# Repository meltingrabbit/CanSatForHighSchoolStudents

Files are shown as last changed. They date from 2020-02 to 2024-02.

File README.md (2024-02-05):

<!-- README.md -->
# 高校生のためのCanSat開発キット
CanSat for High School Students  
高校生のためのCanSat開発キット

**最新版の開発・メンテはフォーク先の [ut-issl/CanSatForHighSchoolStudents](https://github.com/ut-issl/CanSatForHighSchoolStudents) にて行われています．**

## リンク
[GitHub](https://github.com/meltingrabbit/CanSatForHighSchoolStudents)  
[Web Page](https://meltingrabbit.github.io/CanSatForHighSchoolStudents/)

## 概要
+ 高校生向け缶サット開発キット
+ [Arduino Nano Every](https://store.arduino.cc/usa/nano-every-with-headers)を想定
	- Arduino Nanoでも可能だが，よりSRAMの多いEveryを用いたほうがよい．

### Ver.2.2 （2023年版）
Ver.2.1 から，マイクを追加するなどのマイナーアップデートをしたバージョン．

### Ver.2.1 （2022年版）
Ver.2 から，半導体不足等で入手困難なセンサ類を変更したバージョン．

### Ver.2 （2021年版）
+ Ver.1で難易度の高かった配線を簡易化するため，すべての階層に同じマイコンのピンをストレートで伸ばしたもの．
+ これにより，層の順番の変更や，取捨選択が可能となった．

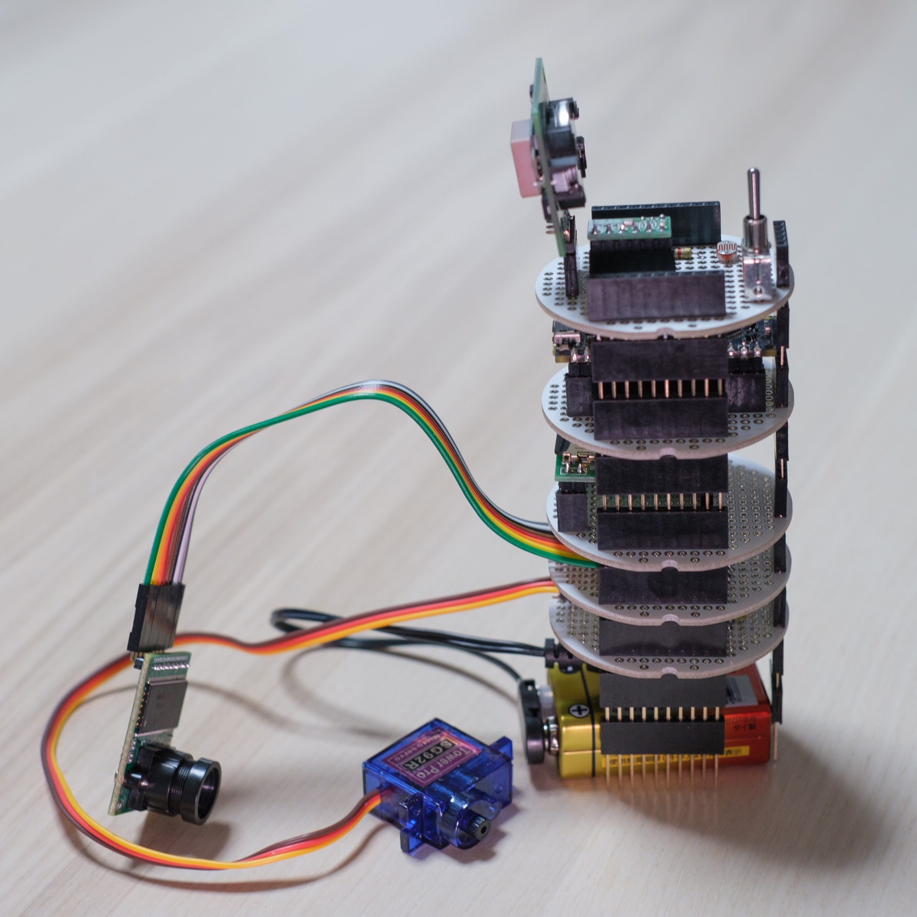
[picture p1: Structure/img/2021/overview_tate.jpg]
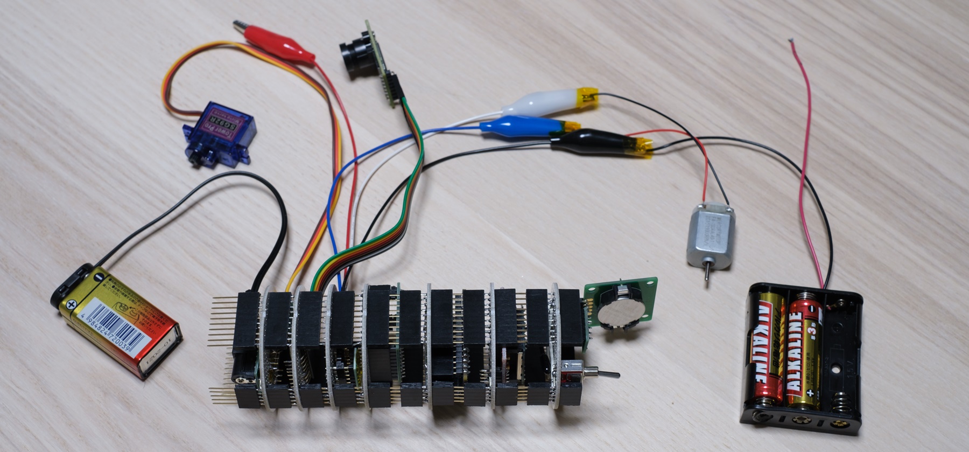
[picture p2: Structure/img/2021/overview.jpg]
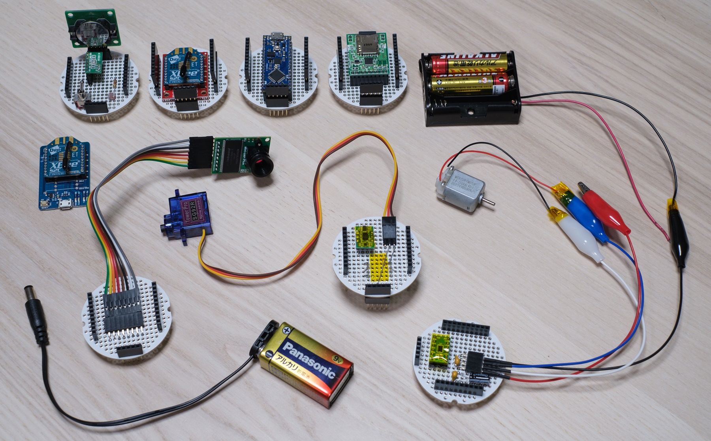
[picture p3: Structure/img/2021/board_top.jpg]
  

### Ver.1 （2020年版）
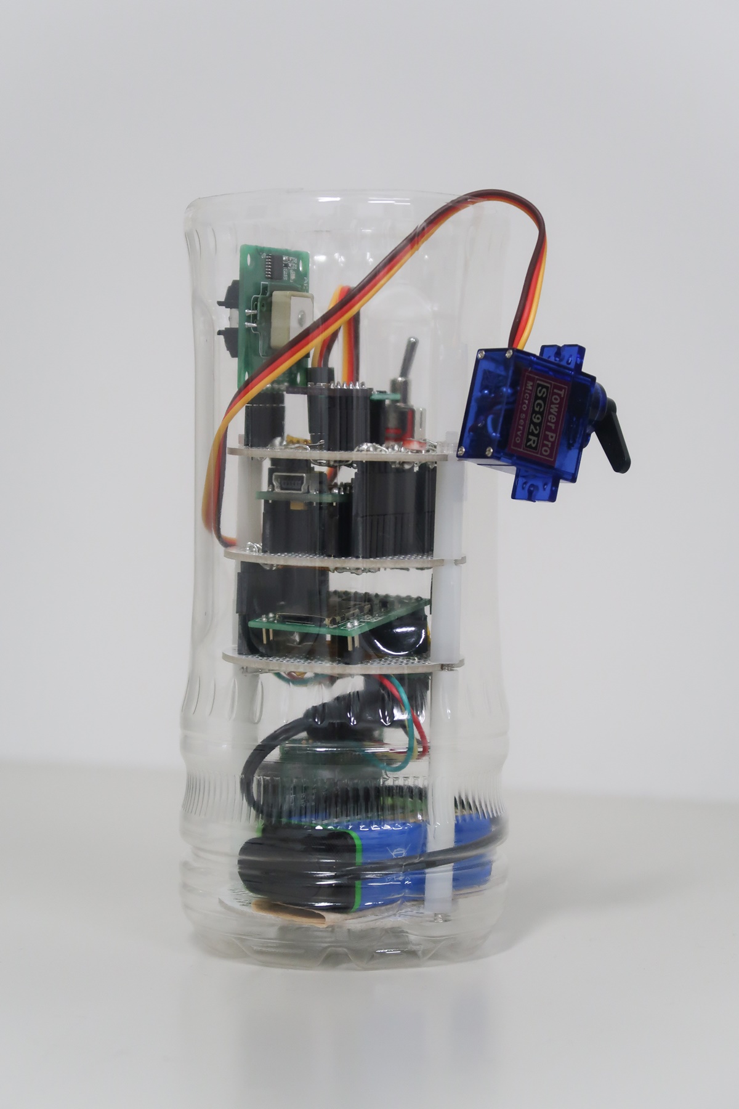
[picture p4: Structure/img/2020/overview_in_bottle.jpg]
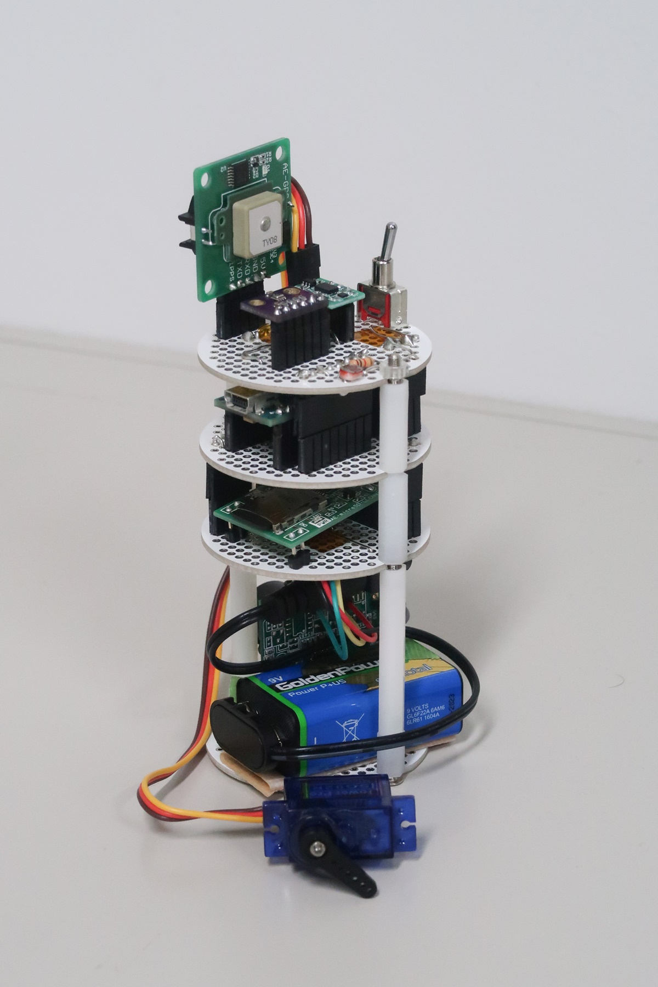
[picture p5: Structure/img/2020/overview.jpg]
 
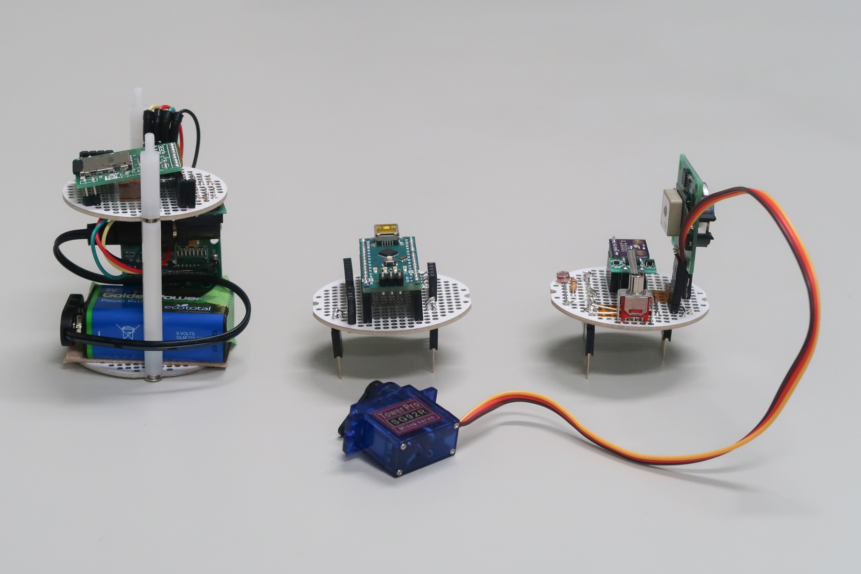
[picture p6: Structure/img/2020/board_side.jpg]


### 利用について
本資料の活用については制限しておりませんが，その際には以下までご一報いただければ幸いです．
+ melting.rabbit.mr[at]gmail.com

## 搭載機器
機器の詳細な型番などは[パーツリスト](./Structure/PartsList)を参照のこと．

### センサ
+ GPS
+ 9軸センサ
+ 高度計（気圧計）
+ 温湿度計
+ 光センサ
+ カメラ
+ マイク

### アクチュエータ
+ サーボモータ
+ DCモータ

### 通信機
+ XBee

### ストレージ
+ SDカード

## 資料一覧
+ `./Arduino` ：サンプルコードとその設定など
	- [Arduinoについて](./Arduino/)
	- 機器のテストコード（動作試験）
		* [GPSの単体テスト](./Arduino/Test_GPS)
		* [9軸センサ (IMU) の単体テスト (BMX055)](./Arduino/Test_IMU)
		* [9軸センサ (IMU) の単体テスト (Pololu MinIMU-9 v5)](./Arduino/Test_IMU_Pololu)
		* [高度計（気圧計）・温湿度計の単体テスト](./Arduino/Test_Barometer_Thermohygrometer)
		* [光センサの単体テスト](./Arduino/Test_Light)
		* [カメラの単体テスト](./Arduino/Test_Camera2)
		* [マイクの単体テスト](./Arduino/Test_Microphone)
		* [サーボモータの単体テスト](./Arduino/Test_Servo)
		* [DCモータの単体テスト](./Arduino/Test_DCMotor)
		* [SDカードの単体テスト](./Arduino/Test_SD)
		* [XBee（無線通信機）の単体テスト](./Arduino/Test_XBee)
		* 過去
			+ [カメラ（2020年使用版）の単体テスト](./Arduino/Test_Camera_2020)
			+ [高度計（気圧計）（2020年使用版）の単体テスト](./Arduino/Test_Barometer)
	- 機器のテストコード（複数使用）
		* [全機器の統合状態のテスト](./Arduino/Test)
		* [光センサを４並列にした光方向センサ](./Arduino/Test_Light_x4)
		* [サーボモータの２並列版](./Arduino/Test_Servo_x2)
		* [DCモータの２並列版](./Arduino/Test_DCMotor_x2)
	- プログラミング講習
		* [00. 事前準備](./Arduino/ProgrammingTutorial00_Preparation)
		* [01. HelloWorld](./Arduino/ProgrammingTutorial01_HelloWorld)
		* [02. Variable](./Arduino/ProgrammingTutorial02_Variable)
		* [03. Operator](./Arduino/ProgrammingTutorial03_Operator)
		* [04. If Else](./Arduino/ProgrammingTutorial04_IfElse)
		* [05. Loop](./Arduino/ProgrammingTutorial05_Loop)
		* [06. Function](./Arduino/ProgrammingTutorial06_Function)
		* [07. Device1 （高度計）](./Arduino/ProgrammingTutorial07_Device1)
		* [08. Device2 （方位磁石）](./Arduino/ProgrammingTutorial08_Device2)
		* [09. Device3 （サーボモータの利用）](./Arduino/ProgrammingTutorial09_Device3)
		* [10. Application （明るさ計）](./Arduino/ProgrammingTutorial10_Application)
	- 実装例
		* [明るさ計](./Arduino/App_LightMeter)
+ `./Schematic` ：[回路図](./Schematic)
+ `./Structure` ：[構造など](./Structure)
	- [パーツリスト](./Structure/PartsList)
	- [ユニ基板詳細](./Structure/board)
	- [電源スイッチ](./Structure/switch)
	- [テスタ](./Structure/tester)
+ `./Archives` ：アーカイブ
	- [2020年02月22～23日 缶サットHigh School 「缶サット電子系講座」](./Archives/2020-02-22_Fukui)
	- [2021年06月19～20日 缶サットHigh School 「缶サット構造系講座」](./Archives/2021-06-19_Fukui)
	- [2022年03月19～20日 缶サットHigh School 「缶サット電子系講座」](./Archives/2022-03-19_Fukui)
	- [2023年02月18～19日 缶サットHigh School 「缶サット電子系講座」](./Archives/2023-02-18_Fukui)

## ブログ
+ [【CanSat】缶サット甲子園を目指す高校生向け電子系講座 2020年度版 @福井 [2020/02/23]](https://meltingrabbit.com/blog/article/2020022301/)
+ [【CanSat】缶サット甲子園を目指す高校生向け構造系講座 2020年度版 @福井 [2020/10/25]](https://meltingrabbit.com/blog/article/2020102501/)
+ [【CanSat】缶サット甲子園を目指す高校生向け電子系講座 2021年度版 @福井 [2021/02/14]](https://meltingrabbit.com/blog/article/2021021401/)
+ [【CanSat】缶サット甲子園を目指す高校生向け構造系講座 2021年度版 @福井 [2021/06/20]](https://meltingrabbit.com/blog/article/2021062001/)
+ [【CanSat】缶サット甲子園を目指す高校生向け電子系・構造系講座 2022年度版 @福井 [2022/06/19]](https://meltingrabbit.com/blog/article/2022061901/)

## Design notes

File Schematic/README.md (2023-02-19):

# 回路図
詳細は，各機器の動作試験コードのページを参照
+ [GPS](../Arduino/Test_GPS)
+ [9軸センサ](../Arduino/Test_IMU)
+ [高度計（気圧計）・温湿度計](../Arduino/Test_Barometer_Thermohygrometer)
+ [光センサ](../Arduino/Test_Light)
+ [カメラ](../Arduino/Test_Camera2)
+ [マイク](../Arduino/Test_Microphone)
+ [サーボモータ](../Arduino/Test_Servo)
+ [DCモータ](../Arduino/Test_DCMotor)
+ [SDカード](../Arduino/Test_SD)
+ [XBee（無線通信機）](../Arduino/Test_XBee)
+ [全機器の統合状態](../Arduino/Test)
+ 過去
	- [カメラ](../Arduino/Test_Camera_2020)
	- [高度計（気圧計）](../Arduino/Test_Barometer)

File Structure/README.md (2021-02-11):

# 構造
## 概要
+ ユニバーサル基板を用いて配線と構造を組む
+ [詳細画像はこちら](./board)
<!--
![](./overview_in_bottle.jpg)
![](./overview.jpg)
![](./board_side.jpg)
![](./board_top.jpg)
-->

### Ver.2 （2021年版）
+ Ver.1で難易度の高かった配線を簡易化するため，すべての階層に同じマイコンのピンをストレートで伸ばしたもの．
+ これにより，層の順番の変更や，取捨選択が可能となった．

  

マイコン層のピンアサインは以下の通り．
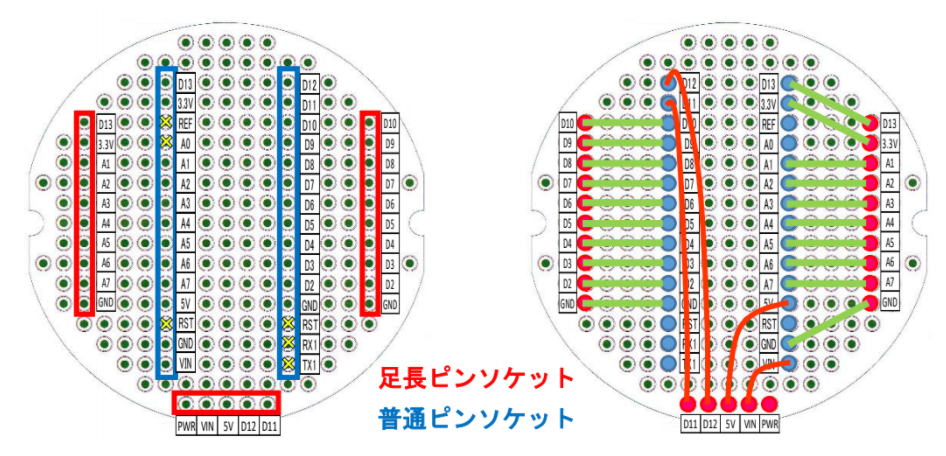
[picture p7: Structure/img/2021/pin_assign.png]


### Ver.1 （2020年版）
 


## パーツ
[電源スイッチ](./switch)

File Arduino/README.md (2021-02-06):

# Arduinoについて
## 概要
[Arduino](https://www.arduino.cc/)とは，電子工作初心者にも使いやすいマイコンであり，C言語風のプログラムによってソフトウェアを書く．  
特徴は以下．

+ 電子工作のデファクトであり，対応するセンサも多い．
+ コミュニティが広く，サンプルコードなどがたくさん出回っている．
+ 5V系であるため，近年主流となっている3.3V系のセンサを用いる場合はレベル変換が必要．

様々な種類があるが，CanSatには小型なNanoシリーズが適している．

## Arduino Nano
[Arduino Nano](https://store.arduino.cc/usa/arduino-nano)．  
標準的なUNOより小型なボード．

- ATmega328P搭載
	- Flashメモリ: 32 KB 内2KBはブートローダーで使用
	- SRAM: 2 KB
	- EEPROM: 1 KB
	- Clock Speed: 16 MHz
- 動作電圧: 5 V
- 入力電源電圧(推奨): 7～12 V
- デジタル入出力ピン: 14本
- PWMチャンネル: 6本
- アナログ入力チャンネル: 8本
- 直流電流(1ピン当り最大): 40 mA
- 直流電流(3.3Vピン、1ピン当り最大): 50 mA

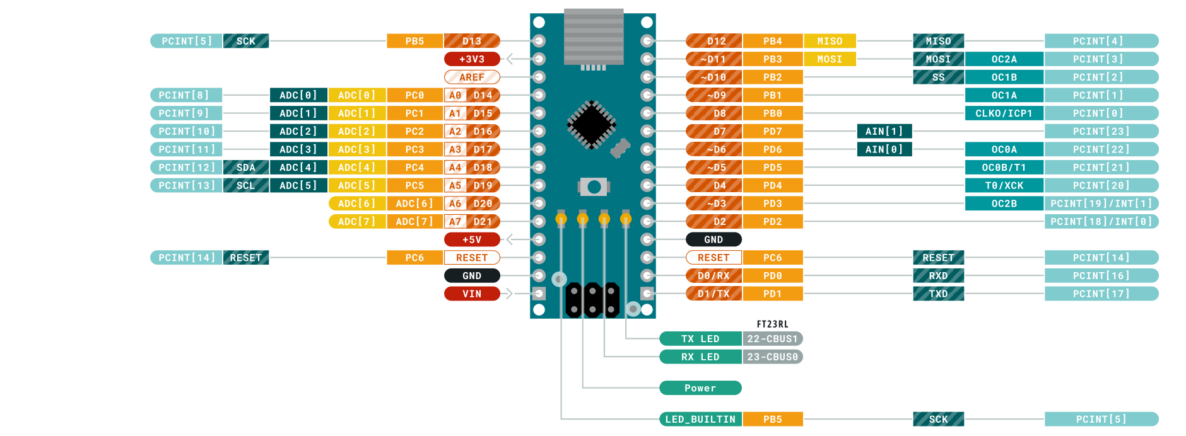
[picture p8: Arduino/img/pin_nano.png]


## Arduino Nano Every
[Arduino Nano Every](https://store.arduino.cc/usa/nano-every-with-headers)．  
Arduino Nanoと同じフットプリントで高性能になった，Arduino Nanoの後継機である．

CanSatとしては，Nanoと比べてSRAMが3倍になっているのが嬉しい．  
これにより，たくさんのセンサを同時に駆動できるようになった．

- ATMega4809搭載
	- CPU Flash Memory 48 KB
	- SRAM 6KB
	- EEPROM 256byte
- 動作電圧：5 V
- 外部入力電源電圧（推奨）: 7 ～ 12 V
- I/Oピン最大電流：20 mA
- 3.3 Vピン最大電流：50 mA
- 動作周波数：20 MHz
- PWM ピン数；5 （D3, D5, D6, D9, D10）
- UART x 1
- SPI x 1
- I2C x 1
- アナログ入力ピン数 x 8 （ADC 10 bit）
- 寸法；45 mm x 18 mm

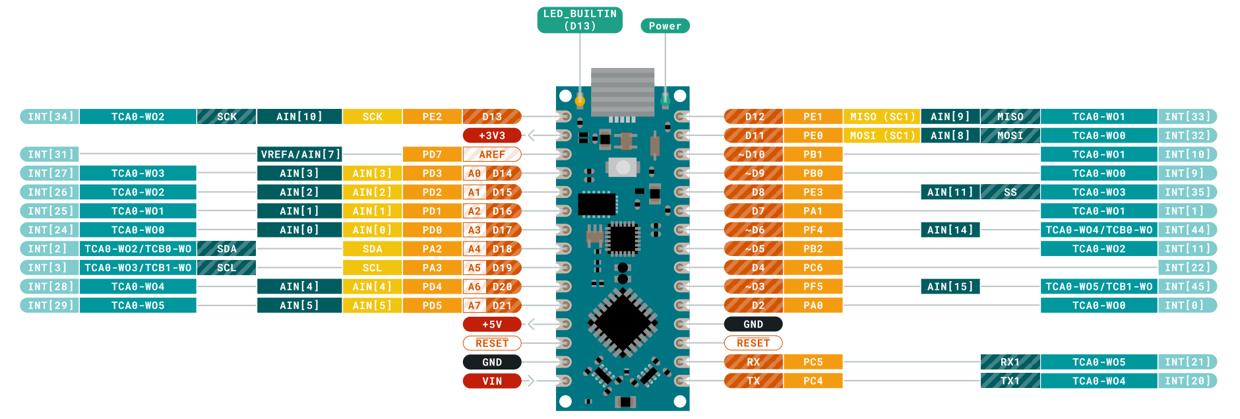
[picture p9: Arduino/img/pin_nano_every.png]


## GitHubへのリンク
[GitHub](https://github.com/meltingrabbit/CanSatForHighSchoolStudents/tree/master/Arduino)

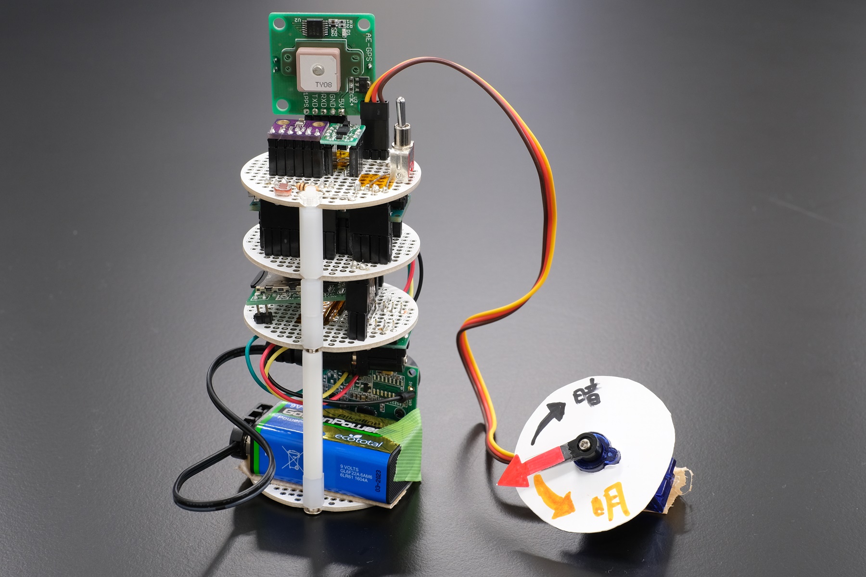
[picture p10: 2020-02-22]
Arduino/App_LightMeter/img/overview.JPG

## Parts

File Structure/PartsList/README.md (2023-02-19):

# パーツリスト
## マイコン
| パーツ名 | 型番 | 概要 | 購入先URL |
| :--- | :--- | :--- | :--- |
| Arduino Nano Every | 	ARDUINO-7630049201552 |  | [SWITCH SCIENCE](https://www.switch-science.com/catalog/6199/) |
| Arduino Nano | ARDUINO-A000005 |  | [SWITCH SCIENCE](https://www.switch-science.com/catalog/2554/) |

+ Arduino NanoはSRAMが2KBと極めて少なく，高度なことをするのは厳しいので，後継機でありSRAMが6KBの[Arduino Nano Every](https://www.switch-science.com/catalog/6199/)の方が好ましいだろう．
+ また，個人的にはESP32系列（例えば[ESPr® Developer 32](https://www.switch-science.com/catalog/3210/)）は更に高性能でWiFiやBLEが搭載されているので，非常に使い勝手が良いと思っている（Arduino互換ではあるが，若干異なるので注意）．

## センサ
| パーツ名 | 型番 | 概要 | 購入先URL |
| :--- | :--- | :--- | :--- |
| GPS | AE-GYSFDMAXB | 実装参考は[こちら](../../Arduino/Test_GPS) | [秋月電子通商](http://akizukidenshi.com/catalog/g/gK-09991/) |
| 9軸センサ | AE-BMX055 | 実装参考は[こちら](../../Arduino/Test_IMU) | [秋月電子通商](http://akizukidenshi.com/catalog/g/gK-13010/) |
| 9軸センサ | Pololu MinIMU-9 v5 | 実装参考は[こちら](../../Arduino/Test_IMU_Pololu) | [スイッチサイエンス](https://www.switch-science.com/catalog/2658/) |
| 気圧計・温湿度計 | BME280 | 実装参考は[こちら](../../Arduino/Test_Barometer_Thermohygrometer) | [秋月電子通商](https://akizukidenshi.com/catalog/g/gK-09421/)<br>[スイッチサイエンス](https://www.switch-science.com/catalog/2236/) |
| 光センサ | MI527 | CdSセルを使用したセンサ<br>実装参考は[こちら](../../Arduino/Test_Light) | [秋月電子通商](http://akizukidenshi.com/catalog/g/gI-00110/) |
| カメラ | Arducam Mini 2MP Plus | 実装参考は[こちら](../../Arduino/Test_Camera2) | [SWITCH SCIENCE](https://www.switch-science.com/catalog/3780/) |
| マイク | 高感度マイクアンプキット | 実装参考は[こちら](../../Arduino/Test_Microphone) | [秋月電子通商](https://akizukidenshi.com/catalog/g/gK-05757/) |

## アクチュエータ
| パーツ名 | 型番 | 概要 | 購入先URL |
| :--- | :--- | :--- | :--- |
| サーボモータ | SG92R | 制御角±90°のサーボモータ<br>実装参考は[こちら](../../Arduino/Test_Servo) | [秋月電子通商](http://akizukidenshi.com/catalog/g/gM-08914/) |
| DCモータ | FA-130RA-2270L | 1.5-3VのDCモータ<br>実装参考は[こちら](../../Arduino/Test_DCMotor) | [秋月電子通商](https://akizukidenshi.com/catalog/g/gP-09169/) |
| DCモータ | RS-385PH-4045 | 3-9VのDCモータ<br>実装参考は[こちら](../../Arduino/Test_DCMotor) | [秋月電子通商](https://akizukidenshi.com/catalog/g/gP-06439/) |

## 通信機
| パーツ名 | 型番 | 概要 | 購入先URL |
| :--- | :--- | :--- | :--- |
| XBee S2C / ワイヤアンテナ型 | DIGI-XB24-CAWIT-001 | 屋外で長距離通信できる通信機<br>実装参考は[こちら](../../Arduino/Test_XBee) | [SWITCH SCIENCE](https://www.switch-science.com/catalog/4089/) |
| XBeeエクスプローラ5Vマイコン用 | SFE-WRL-11373 | XBeeの5Vへのレベル変換 兼 ピッチ変換 | [SWITCH SCIENCE](https://www.switch-science.com/catalog/1166/) |
| XBee USB アダプター rev.2 | SSCI-034951 | XBeeとPCの接続用 | [SWITCH SCIENCE](https://www.switch-science.com/catalog/3495/) |

## その他基板実装パーツ
| パーツ名 | 型番 | 概要 | 購入先URL |
| :--- | :--- | :--- | :--- |
| 1kΩ抵抗 |  | 光センサ用負荷抵抗 |  |
| 10kΩ抵抗 |  | カメラ通信ラインの分圧用 |  |
| ピンソケット(40P) | SFE-PRT-00115 | センサやマイコンと基板間にはんだしておくソケット<br>基板間の電源・通信ライン接続にも用いる | [SWITCH SCIENCE](https://www.switch-science.com/catalog/505/) |
| 足の長いピンソケット(10P)| SSCI-014182 | 基板間の電源・通信ライン接続用 | [SWITCH SCIENCE](https://www.switch-science.com/catalog/1418/) |
| ピンヘッダ 1×40(40P) | PH-1x40SG | サーボのコネクタと基板間にはんだしておくピン<br>基板間の電源・通信ライン接続にも用いる | [秋月電子通商](http://akizukidenshi.com/catalog/g/gC-00167/) |
| microSDカードスロット | AE-microSD-LLCNV | microSDカードへの書き込み・読み取り回路基板<br>実装参考は[こちら](../../Arduino/Test_SD) | [秋月電子通商](http://akizukidenshi.com/catalog/g/gK-14015/) |
| トグルスイッチ | 2MS1-T1-B4-VS2-Q-E | 電源ON/OFF用スイッチ<br>実装参考は[こちら](../switch) | [秋月電子通商](http://akizukidenshi.com/catalog/g/gP-00300/) |
| ターミナルブロック | WJEK254-2.54-02P-122-00A | バッテリの基板接続用 | [秋月電子通商](https://akizukidenshi.com/catalog/g/gP-14611/) |
| DCジャック | AE-DC-POWER-JACK-DIP | DCプラグ接続用コネクタ基板 | [秋月電子通商](http://akizukidenshi.com/catalog/g/gK-05148/) |
| ジャンパワイヤ(オス-オス) | BBJ-65 | カメラ等を直接配線する用 | [秋月電子通商](http://akizukidenshi.com/catalog/g/gC-05159/) |
| メッキ線 | P-13310 | 基板にはんだ固定する導通経路用 | [秋月電子通商](http://akizukidenshi.com/catalog/g/gP-13310/) |
| 被覆線 |  | ジャンプ配線に用いる |  |
| カプトンテープ |  | 導通防止箇所に貼るテープ |  |

## 構造部材
| パーツ名 | 型番 | 概要 | 購入先URL |
| :--- | :--- | :--- | :--- |
| 丸型基板 | AE-50.8mm-TH | 回路実装基板 | [秋月電子通商](http://akizukidenshi.com/catalog/g/gP-08758/) |
| スペーサー(30mm) | TP-30 | 基板間締結用 | [秋月電子通商](http://akizukidenshi.com/catalog/g/gP-07572/) |
| スペーサー(20mm) | TP-20 | 基板間締結用 | [秋月電子通商](http://akizukidenshi.com/catalog/g/gP-07570/) |
| プラスチックナット・ボルト | P-01885 | 基板間締結用 | [秋月電子通商](http://akizukidenshi.com/catalog/g/gP-01885/) |

## 周辺機器
| パーツ名 | 型番 | 概要 | 購入先URL |
| :--- | :--- | :--- | :--- |
| ＤＣプラグ付バッテリースナップ | BS-IR-1/150MM+DC5.5X2.1X10MM | 電池とDCジャックの接続用 | [秋月電子通商](http://akizukidenshi.com/catalog/g/gP-07356/) |
| 9Vアルカリ角電池 | GL6F22A | 缶サット単体での起動用 | [秋月電子通商](http://akizukidenshi.com/catalog/g/gB-03257/) |
| 単3アルカリ乾電池 |  | DCモータの外部電源用 |  |
| 電池ボックス |  | 単3アルカリ乾電池の収納用 |  |
| microSDカード |  | ログデータ・画像データ保存用（16GB以下が安全） |  |
| ACアダプタ | GF12-US1210 | 缶サット単体での起動用(電池を消耗したくないときコンセントから電源を取る) | [秋月電子通商](http://akizukidenshi.com/catalog/g/gM-01804/) |
| usbケーブル | USBcable A-microB | PCとArduino Nano Every，PCとXBeeの接続用 | [秋月電子通商](https://akizukidenshi.com/catalog/g/gC-07607/) |
| usbケーブル | USBcable A-miniB | PCとArduino Nanoの接続用 | [秋月電子通商](http://akizukidenshi.com/catalog/g/gC-07606/) |

## 工具，器具など
工具の型番はあくまで例であり，好きなものを準備すること．

| パーツ名 | 型番 | 概要 | 購入先URL |
| :--- | :--- | :--- | :--- |
| テスタ |  | 導通チェック用など |  |
| はんだごて | 白光 FX600-01 | はんだ付け用 | [ヨドバシカメラ](https://www.yodobashi.com/product/100000001001987046/) |
| こて台 | 白光 633-01 | はんだ付け用<br>個人的にはスポンジタイプより金属タイプが好き．フラックスも含むし． | [ヨドバシカメラ](https://www.yodobashi.com/product/100000001001987509/) |
| フラックス | 白光 FX600-01 | はんだ付け用<br>賛否両論あるが，フラックスがあったほうが圧倒的に楽だと思う（とくに鉛フリーで） | [ヨドバシカメラ](https://www.yodobashi.com/product/100000001001885214/) |
| フラックス洗浄剤 |  | はんだ付け用 |  |
| はんだ | 太洋電機産業 SD60 | はんだ付け用 | [ヨドバシカメラ](https://www.yodobashi.com/product/100000001003578754/) |
| はんだ | 太洋電機産業 SF-B1004 | はんだ付け用 | [ヨドバシカメラ](https://www.yodobashi.com/product/100000001004866812/) |
| はんだハンダ吸い取り線 | 太洋電機産業 CP-15Y | はんだ付け用 | [ヨドバシカメラ](https://www.yodobashi.com/product/100000001001987609/) |
| はんだ吸い取り器 |  | はんだ付け用 |  |
| ニッパー |  |  |  |
| ラジオペンチ |  |  |  |
| ワイヤーストリッパ |  |  |  |

# パーツリスト（過去使用版）
## センサ
| パーツ名 | 型番 | 概要 | 購入先URL |
| :--- | :--- | :--- | :--- |
| 気圧計 | GY-BMP280-3.3 | 実装参考は[こちら](../../Arduino/Test_Barometer) | [LED PARADISE](https://www.led-paradise.com/product/2334) |
| TTLシリアルJPEGカメラ | ADA-397 | 実装参考は[こちら](../../Arduino/Test_Camera_2020) | [SWITCH SCIENCE](https://www.switch-science.com/catalog/1241/) |

## その他基板実装パーツ
| パーツ名 | 型番 | 概要 | 購入先URL |
| :--- | :--- | :--- | :--- |
| <del>ロングピンソケット 1×42(42P)</del> | <del>FHU-1x42SG</del> | <del>センサやマイコンと基板間にはんだしておくソケット<br>基板間の電源・通信ライン接続にも用いる</del><br> → ピンがゆるいので，他の商品がベター | <del>[秋月電子通商](http://akizukidenshi.com/catalog/g/gC-05779/)</del> |

### GitHubへのリンク
[GitHub](https://github.com/meltingrabbit/CanSatForHighSchoolStudents/tree/master/Structure/PartsList)

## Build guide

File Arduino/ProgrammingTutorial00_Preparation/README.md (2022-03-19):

# プログラミング講習 00. 事前準備
## 概要
+ Arduino IDE でプログラミングを始めるための事前準備
+ Arduino については [こちら](../)
+ IDE（開発環境）のダウンロードはこちら
	- https://www.arduino.cc/en/main/software

## 説明スライド
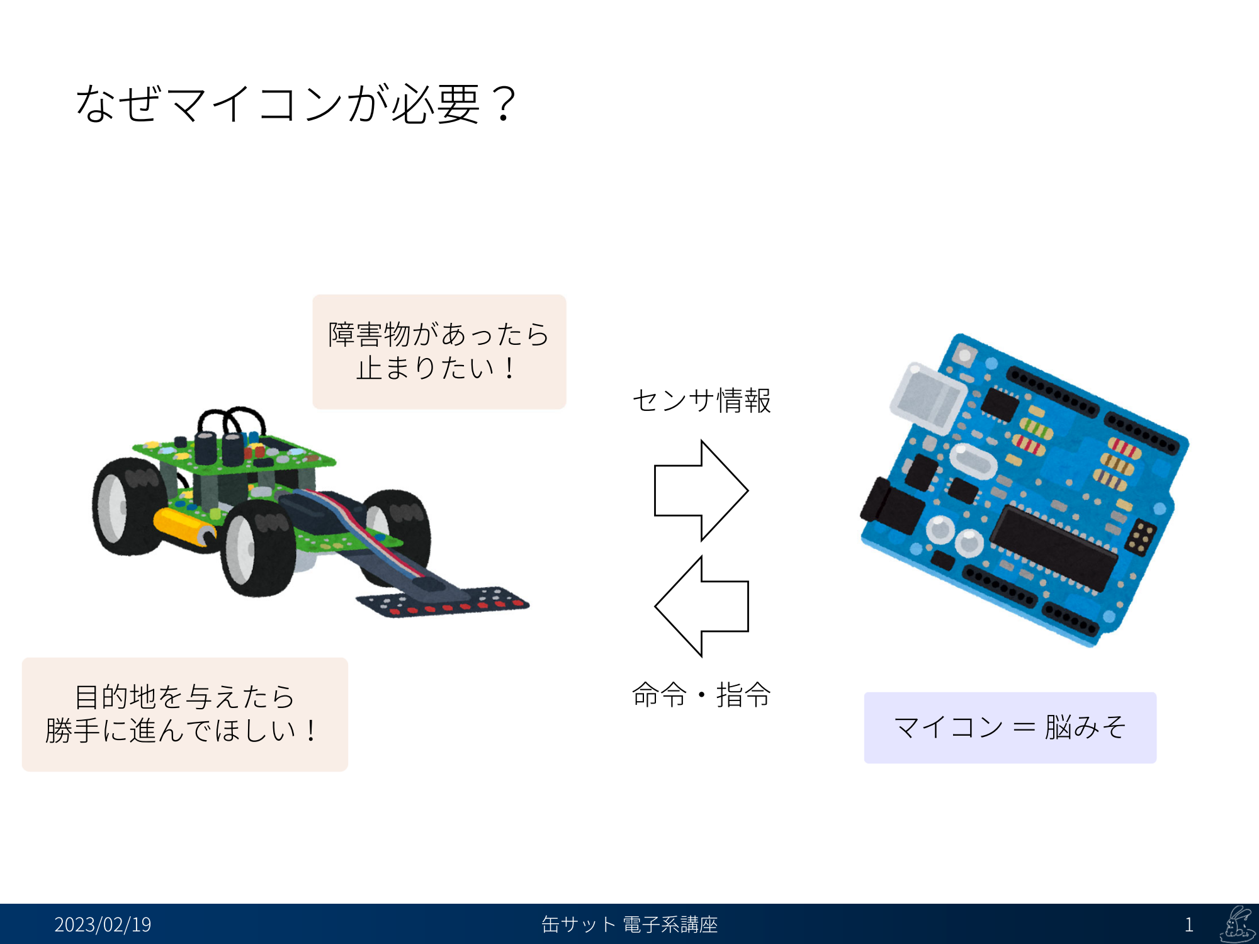
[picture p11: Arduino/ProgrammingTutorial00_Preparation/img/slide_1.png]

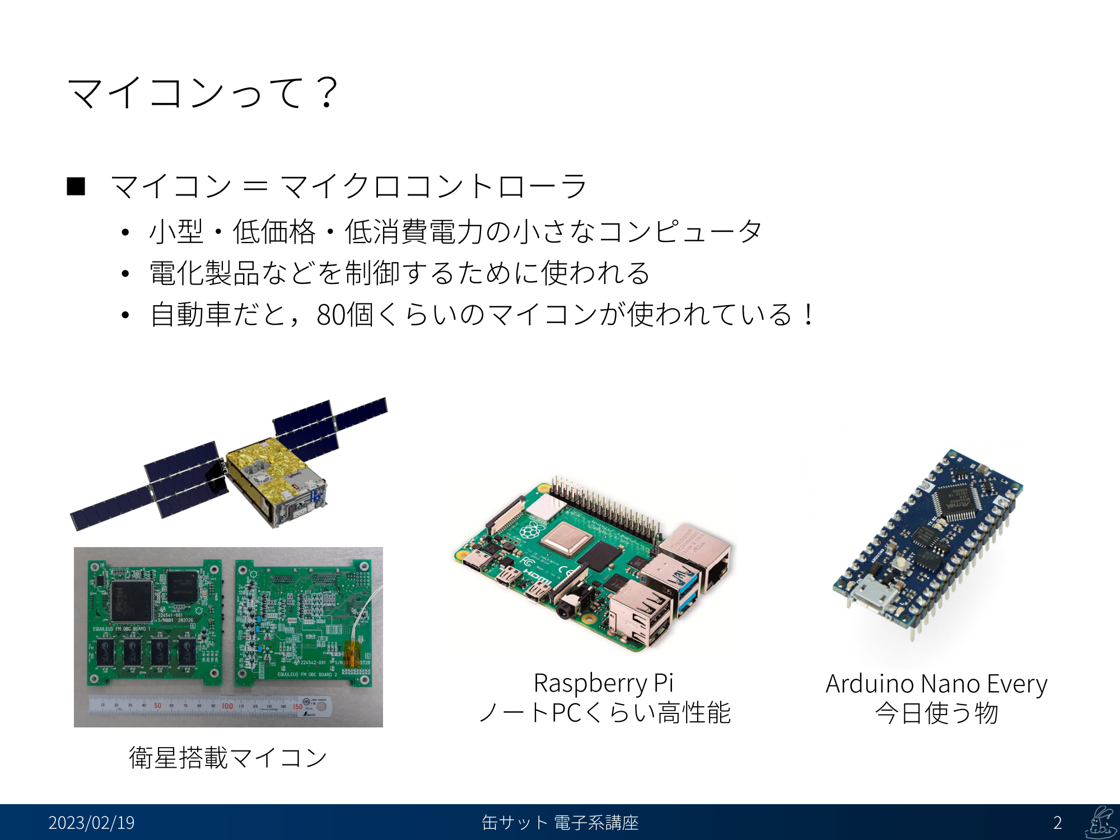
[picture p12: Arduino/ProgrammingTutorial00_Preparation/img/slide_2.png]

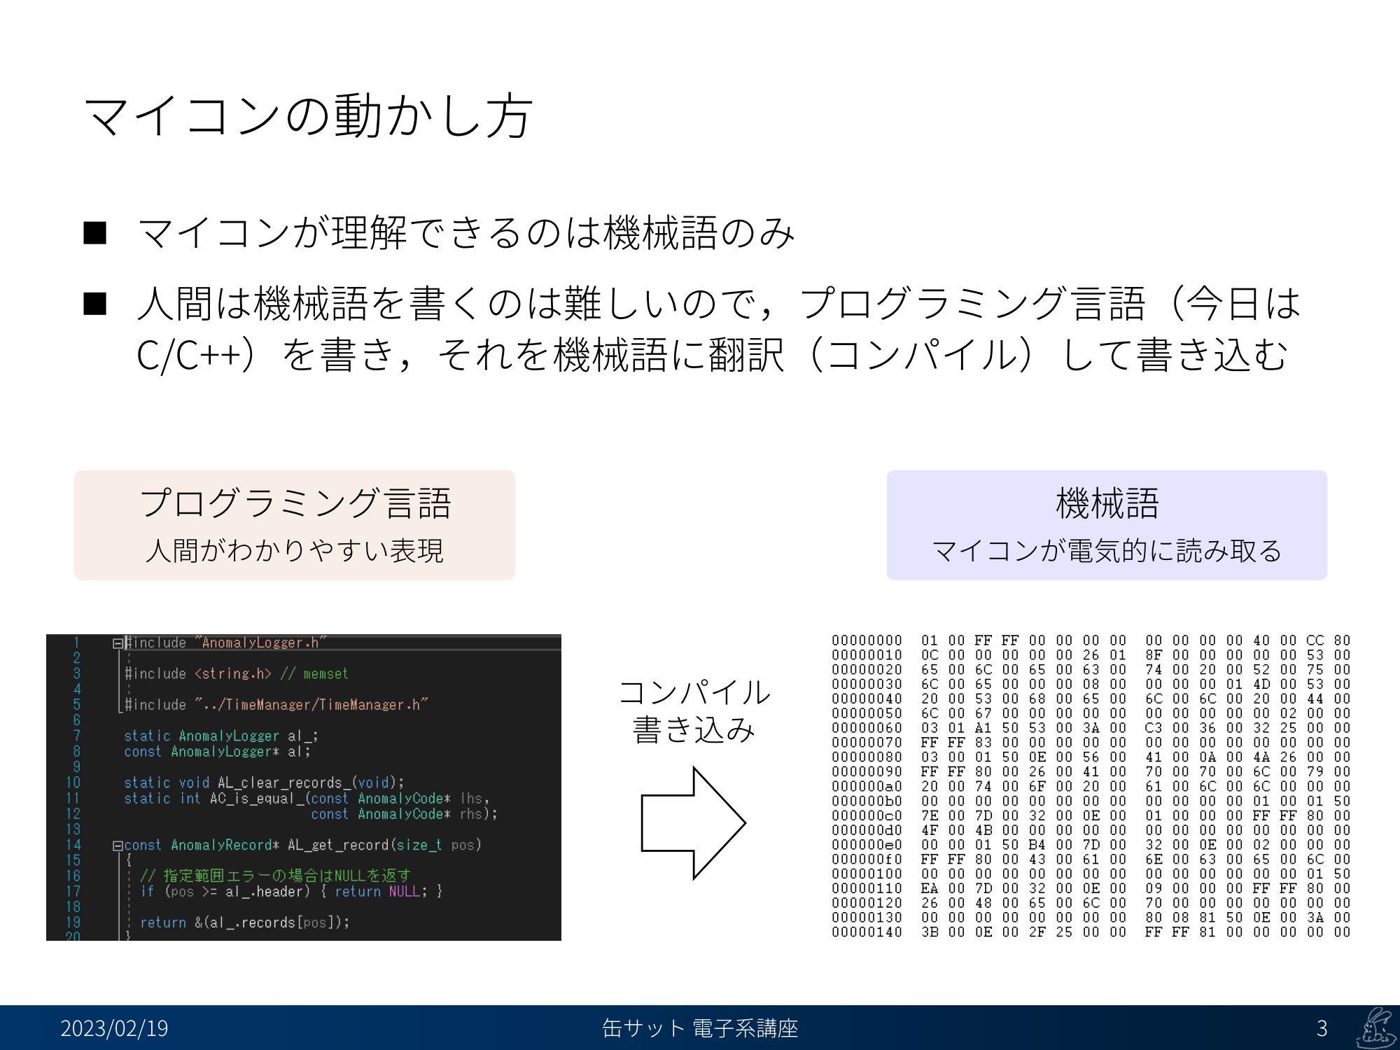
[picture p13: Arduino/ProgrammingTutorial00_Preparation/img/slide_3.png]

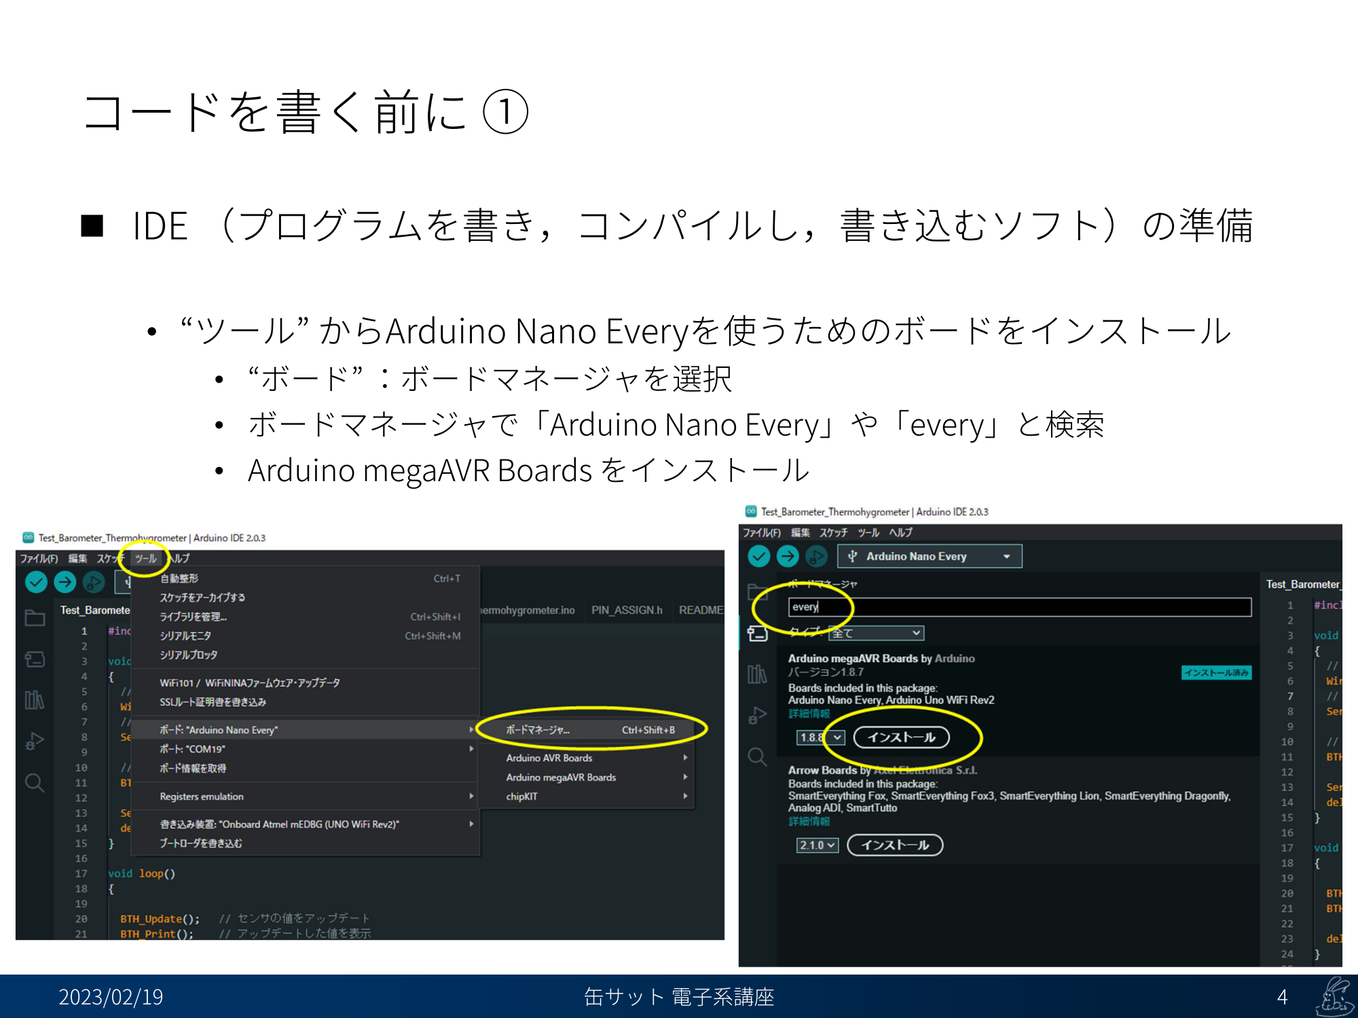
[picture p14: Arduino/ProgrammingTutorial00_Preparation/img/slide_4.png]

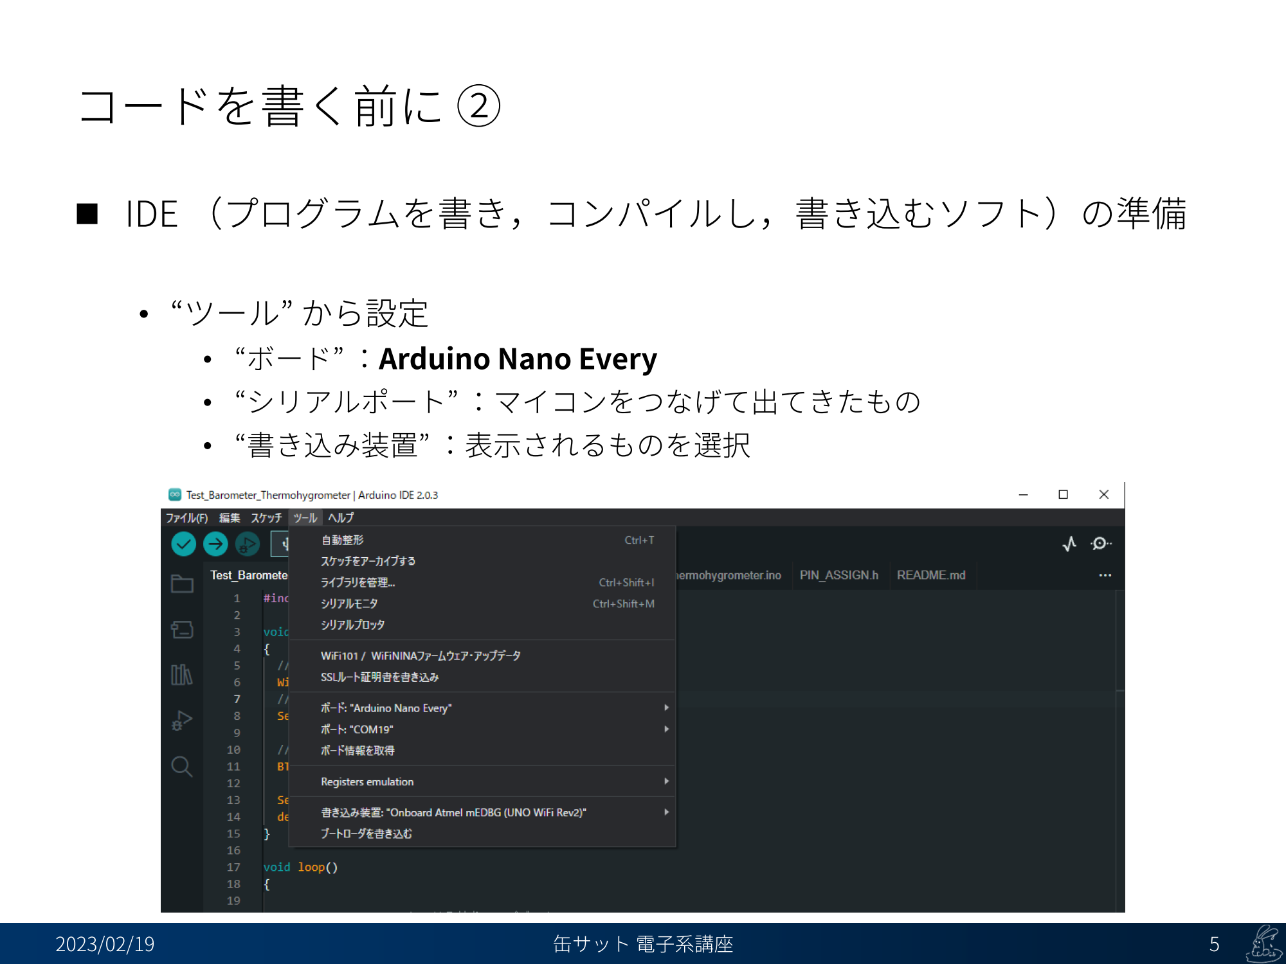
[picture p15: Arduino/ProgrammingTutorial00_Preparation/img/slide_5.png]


※ `書込装置（書き込み装置）` については，2022/03/19現在，「Onboard Atmel mEDBG (UNO WiFi Rev2)」であることもあります．

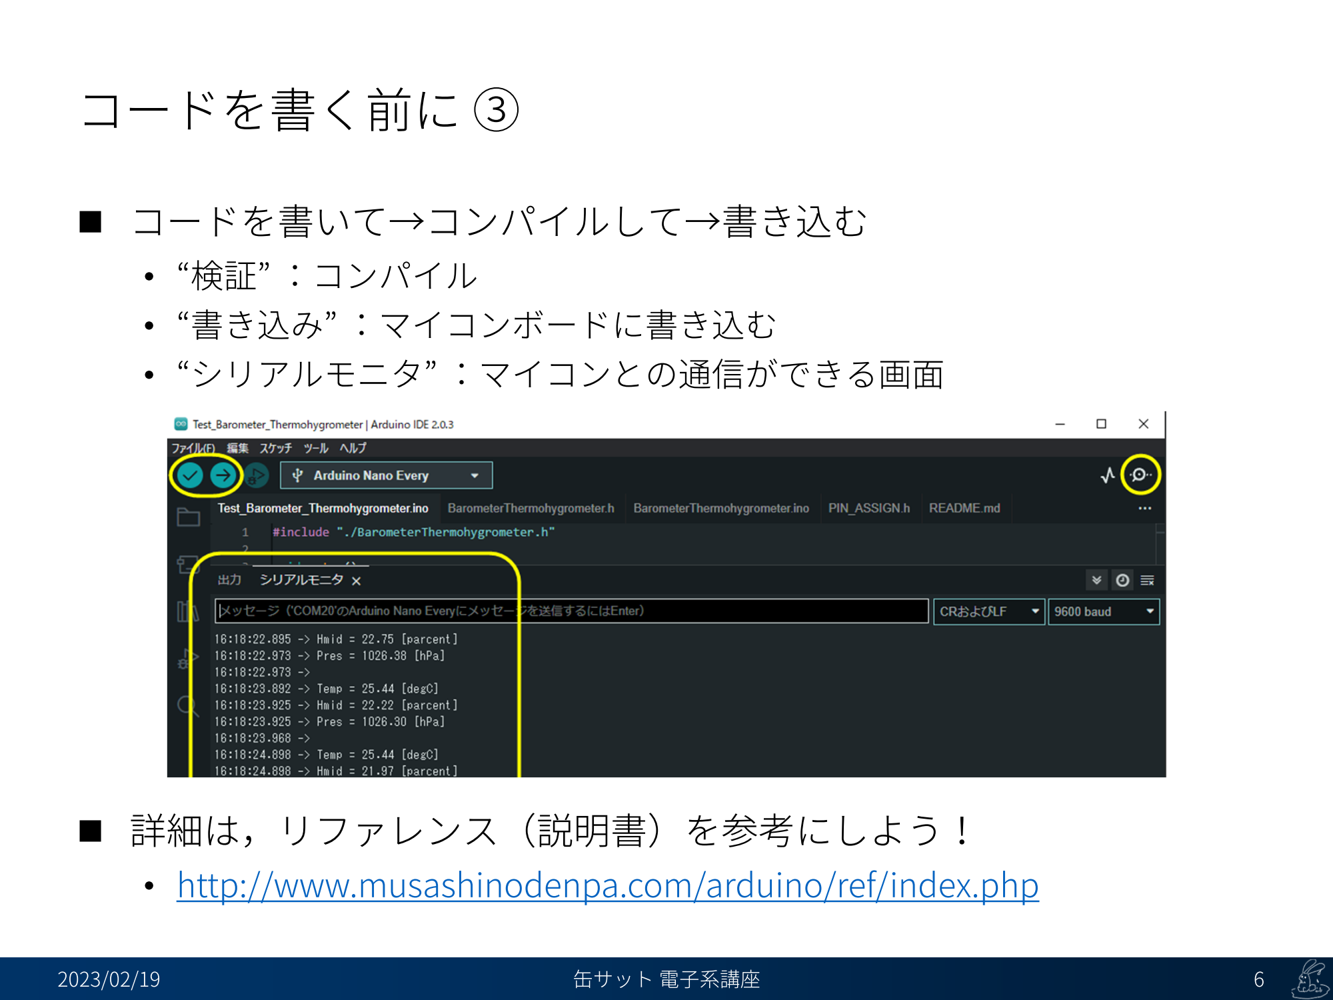
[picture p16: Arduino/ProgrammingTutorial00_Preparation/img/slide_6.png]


## リファレンス
詳細な説明はリファレンス（説明書）を参考にしよう！  
[http://www.musashinodenpa.com/arduino/ref/index.php](http://www.musashinodenpa.com/arduino/ref/index.php)

## ソースコードへのリンク
[GitHub](https://github.com/meltingrabbit/CanSatForHighSchoolStudents/tree/master/Arduino/ProgrammingTutorial00_Preparation)

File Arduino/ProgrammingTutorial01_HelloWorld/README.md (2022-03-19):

# プログラミング講習 01. Hello World
## 概要
+ “Hello World” とは，プログラミングで最初に行う例題
	- 手始めに文字だけ表示し，Arduinoのプログラミングの大枠を知ろう！

## ソースコード
```cpp
void setup()                        // 最初に実行される
{
  Serial.begin(9600);               // 通信速度 9600 bps でPCとシリアル通信開始
  Serial.println("Hello World!!");  // 文字列 "Hello World!!" を出力
  delay(1000);                      // 1000 ms 待つ
  Serial.println("Setup!");         // 文字列 "Setup!" を出力
  delay(1000);                      // 1000 ms 待つ
}

void loop()                         // Setup後，繰り返し実行される
{
  Serial.println(F("Loop!"));       // 文字列 "Loop!" を出力
                                    // F() で囲むと（Fマクロ），使用メモリを抑えることができる（ROMを消費する）
  // Serial.println("Comment");     // "//" で始まる行はコメント行（実行されない）
  delay(1000);                      // 1000 ms 待つ
}
```

+ 文字を変えて試してみよう

## 備考
+ `Serial.print`, `Serial.println` での文字列を `F()` で囲う事により，メモリ使用量を抑えることができる．
	- 代わりにROMを消費するが，メモリ (RAM) の少ないArduinoでは有効な手段である．
+ マイコンのリセットボタンを押すと，プログラムはリセットされ，再びソースコードの最初から実行される．

## リファレンス
詳細な説明はリファレンス（説明書）を参考にしよう！  
[http://www.musashinodenpa.com/arduino/ref/index.php](http://www.musashinodenpa.com/arduino/ref/index.php)

## ソースコードへのリンク
[GitHub](https://github.com/meltingrabbit/CanSatForHighSchoolStudents/tree/master/Arduino/ProgrammingTutorial01_HelloWorld)

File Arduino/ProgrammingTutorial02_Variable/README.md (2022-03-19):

# プログラミング講習 02. 変数
## 概要
+ 変数とは，計算結果を入れておく箱
	- 人間は計算用紙に書いていくが，コンピュータは変数に入れていく
	- “型” という概念があり，箱の種類によって入れられるものが違う

## ソースコード
```cpp
void setup()
{
  Serial.begin(9600);
  String s = "String";          // 文字列のための型 "String" 型変数 "s" に "String" を代入
  Serial.print("String: ");
  Serial.println(s);

  int i = 10;                   // 整数のための型 "int" 型変数 "i" に 10 を代入
  Serial.print("Int: ");
  Serial.println(i);

  float f = 10.0;               // 小数のための型 "float" 型変数 "f" に 10.0 を代入
  Serial.print("Float: ");
  Serial.println(f);
}

void loop()
{
}
```

+ 値を自分で変えて試してみよう
+ 整数は，そのサイズによって， `int8_t`, `uint8_t`, `int16_t`, `uint16_t`, `int32_t`, `uint32_t` と種類がいろいろある．
	- `u` がつくのは正数のみで，つかないものは負数も扱える．
	- 数字が大きいほど大きな数字まで扱うことができる一方，その分，マイコンのメモリ（作業スペース）をたくさん使ってしまう．
+ 小数にも同様に， `float`, `double` と種類があり， `double` の方がより細かな値を扱える．

## リファレンス
詳細な説明はリファレンス（説明書）を参考にしよう！  
[http://www.musashinodenpa.com/arduino/ref/index.php](http://www.musashinodenpa.com/arduino/ref/index.php)

## ソースコードへのリンク
[GitHub](https://github.com/meltingrabbit/CanSatForHighSchoolStudents/tree/master/Arduino/ProgrammingTutorial02_Variable)

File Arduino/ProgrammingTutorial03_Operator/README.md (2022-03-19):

# プログラミング講習 03. 演算子
## 概要
+ 四則演算 ( `+-*/` )，剰余 ( `%` ), その他
	- 他にも， `sqrt` や `sin` , `max` なども
+ 型に注意！
	- 整数同士の演算結果は整数
	- 小数と整数の演算結果は小数
+ キャスト
  - `(型名)数字 or 変数` で，方を変換できる
  - 例: `(float)2` 整数 "2" を小数 "2.0" に変換
  - 例: `(int)2.5` 小数 "2.5" を整数 "2" に変換

## ソースコード
```cpp
void setup()
{
  Serial.begin(9600);

  Serial.print("5+2: ");
  Serial.println(5+2);            // 足し算

  Serial.print("5-2: ");
  Serial.println(5-2);            // 引き算

  Serial.print("5*2: ");
  Serial.println(5*2);            // 掛け算

  Serial.print("5/2: ");
  Serial.println(5/2);            // 整数の割り算（商）

  Serial.print("5/2.0: ");
  Serial.println(5/2.0);          // 小数の割り算

  Serial.print("(float)5/2: ");
  Serial.println((float)5/2);     // 整数 "5" を小数に変換してから，小数の割り算

  Serial.print("(int)(5/2.0): ");
  Serial.println((int)(5/2.0));   // 小数の割り算の結果を整数に変換

  Serial.print("5%2: ");
  Serial.println(5%2);            // 整数の割り算（剰余）

  int a = 5;
  int b = 2;
  Serial.print("a/b: ");
  Serial.println(a/b);            // 整数の割り算（変数同士）

  int c = a / b;                  // 整数の割り算結果を変数 "c" に代入
  Serial.print("c: ");
  Serial.println(c);

  float d = 5;
  float e = 2;
  Serial.print("d/e: ");
  Serial.println(d/e);            // 小数の割り算（変数同士）

  float f = e / d;                // 小数の割り算結果を変数 "f" に代入
  Serial.print("f: ");
  Serial.println(f);

  Serial.print("sin(3.14/2): ");
  Serial.println(sin(3.14/2));    // 三角関数（正弦）

  Serial.print("sqrt(2): ");
  Serial.println(sqrt(2));        // 平方根

  Serial.print("max(2,3): ");
  Serial.println(max(2,3));       // 最大値
}

void loop()
{
}
```

+ 値を自分で変えて試してみよう
+ 型の違いに意識してみよう

## リファレンス
詳細な説明はリファレンス（説明書）を参考にしよう！  
[http://www.musashinodenpa.com/arduino/ref/index.php](http://www.musashinodenpa.com/arduino/ref/index.php)

## ソースコードへのリンク
[GitHub](https://github.com/meltingrabbit/CanSatForHighSchoolStudents/tree/master/Arduino/ProgrammingTutorial03_Operator)

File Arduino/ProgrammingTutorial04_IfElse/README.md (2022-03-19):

# プログラミング講習 04. 条件分岐
## 概要
+ 条件によってプログラムを分岐することができる
	- `if`, `else if`, `else` を使って， `{}` で囲う．
+ 比較演算子
	- `==` : 等しい
	- `!=` : 等しくない
	- `<`, `>` : より大きい，より小さい
	- `<=`, `>=` : 以上，以下
+ 論理演算子
	- `&&` : かつ
	- `||` : または
+ 注意
	- プログラムで，コードのまとまりは `{}` を，式のまとまりは `()` を使う．

## ソースコード
```cpp
void setup()
{
  Serial.begin(9600);

  int a = 10;                         // 整数型 (int) の変数 a に整数 10 を代入

  Serial.println("a == 10 ? :");
  if (a == 10) {                      // a は 10 ？
    Serial.println("  -> a == 10");
  } else {                            // それ以外
    Serial.println("  -> otherwise");
  }

  Serial.println("a != 10 ? :");
  if (a != 10) {                      // a は 10 ではない？
    Serial.println("  -> a != 10");
  } else {                            // それ以外
    Serial.println("  -> otherwise");
  }

  Serial.println("a > 10 or a >= 10 ? :");
  if (a > 10) {                       // a は 10 より大きい？
    Serial.println("  -> a > 10");
  } else if (a >= 10) {               // a は 10 より大きくはないけど， 10 以上？
    Serial.println("  -> a >= 10");
  } else {                            // それ以外
    Serial.println("  -> otherwise");
  }

  Serial.println("(a > 5) && (a < 20) ? :");
  if ((a > 5) && (a < 20)) {          // a は 5 より大きく，かつ， 20 より小さい？
    Serial.println("  -> (a > 5) && (a < 20)");
  } else {                            // それ以外
    Serial.println("  -> otherwise");
  }

  Serial.println("(a > 5) || (a > 20) ? :");
  if ((a > 5) || (a > 20)) {          // a は 5 より大きい，または， 20 より大きい？
    Serial.println("  -> (a > 5) || (a > 20)");
  } else {                            // それ以外
    Serial.println("  -> otherwise");
  }
}

void loop()
{
}
```

+ `a` の値を変えて，想像通りに動くか試してみよう
+ 条件式も変えてみよう

## リファレンス
詳細な説明はリファレンス（説明書）を参考にしよう！  
[http://www.musashinodenpa.com/arduino/ref/index.php](http://www.musashinodenpa.com/arduino/ref/index.php)

## ソースコードへのリンク
[GitHub](https://github.com/meltingrabbit/CanSatForHighSchoolStudents/tree/master/Arduino/ProgrammingTutorial04_IfElse)

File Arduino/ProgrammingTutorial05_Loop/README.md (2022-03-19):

# プログラミング講習 05. ループ
## 概要
+ 繰り返しの処理や，ちょっとずつ処理を変化させたい時につかう．
	- `for` と `while` がある．
+ 注意
	- 意図しない無限ループに陥らないように注意すること！

## ソースコード
```cpp
void setup()
{
  Serial.begin(9600);

  Serial.println("#### FOR ####");
  // for (初期化; 継続条件; 変化式)
  // つまり，
  // 最初に実行される; ループを続けるかの条件; ループの最後に毎回実行される文
  // ↓は，変数 "num" に，最初に 0 を代入し，ループごとに 1 を加え， 10 以下の間 {} の中を繰り返す．
  for (int num = 0; num <= 10; num = num + 1) {
    Serial.print("Loop1: ");
    Serial.println(num);
    delay(100);                   // 100 ms 待つ
  }

  Serial.println("#### FOR BREAK ####");
  for (int num = 0; num <= 10; num = num + 1) {

    if (num == 5) {               // もし， "num" が 5 なら
      break;                      // ループから抜ける
    }

    Serial.print("Loop2: ");
    Serial.println(num);
    delay(100);
  }

  Serial.println("#### WHILE ####");
  int count = 0;
  // while (継続条件)
  // ↓は，変数 "count" が 10 未満の間 {} の中を繰り返す．
  while (count < 10) {
    Serial.print("Loop3: ");
    Serial.println(count);
    delay(100);

    count = count + 1;          // count に 1 を足して， count に代入する
  }

  Serial.println("#### WHILE BREAK ####");
  count = 0;
  while (1) {                   // 無限ループ
    Serial.print("Loop4: ");
    Serial.println(count);
    delay(100);

    count = count + 1;

    if (count >= 10) {          // もし， "count" が 10 以上なら
      break;                    // ループから抜ける
    }
  }
}

void loop()
{
}
```

+ 色んな所を変えてみよう！
	- 自分の想定通り動くかな？

## リファレンス
詳細な説明はリファレンス（説明書）を参考にしよう！  
[http://www.musashinodenpa.com/arduino/ref/index.php](http://www.musashinodenpa.com/arduino/ref/index.php)

## ソースコードへのリンク
[GitHub](https://github.com/meltingrabbit/CanSatForHighSchoolStudents/tree/master/Arduino/ProgrammingTutorial05_Loop)

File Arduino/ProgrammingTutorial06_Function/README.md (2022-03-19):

# プログラミング講習 06. 関数
## 概要
+ 同じ処理をたくさん使う時は，“関数” というものにまとめることができる
	- こうすることで，プログラムの再利用性が高まる
	- プログラム全体が見やすくなる

## ソースコード
```cpp
// はじめに，作る関数を宣言する
// 返り値（計算結果）の型（何もない時はvoid），関数名，引数の型と変数名
void print_number(String str, int i);
int  my_max(int a, int b);

void setup()
{
  Serial.begin(9600);

  int a = 10;
  int b = 20;

  print_number("a", a);
  print_number("b", b);
  int c = my_max(a,b);      // my_max は int 型の変数（つまり整数）を計算結果として返し，それを変数 "c" に代入する
  print_number("c", c);
  print_number("my_max(a,b)", my_max(a,b));   // 関数は入れ子にできる
}

void loop()
{
}

// print_number という関数は，
//   String（文字）と int（整数）の２つの引数をもらう
//   返り値の型は void（何も返さない）
//   もらった値を表示する
void print_number(String str, int i) {
  Serial.print(str);
  Serial.print(": ");
  Serial.println(i);
}

// my_max という関数は，
//   ２つの int（整数）の引数をもらう
//   返り値の型は int
//   大きい数字を返す
int  my_max(int a, int b) {
  int ret = 0;      // 計算結果用に ret という変数を準備しておく
  if (a > b) {
    ret = a;
  } else {
    ret = b;
  }
  return ret;
}
```

+ ソースコードの気になった部分を自分で変更してみて，実行してみよう！
+ 自分で考えた関数を作って動かしてみよう！

## リファレンス
詳細な説明はリファレンス（説明書）を参考にしよう！  
[http://www.musashinodenpa.com/arduino/ref/index.php](http://www.musashinodenpa.com/arduino/ref/index.php)

## ソースコードへのリンク
[GitHub](https://github.com/meltingrabbit/CanSatForHighSchoolStudents/tree/master/Arduino/ProgrammingTutorial06_Function)

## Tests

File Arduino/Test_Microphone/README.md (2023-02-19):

# マイクの単体テストコード
## 概要
マイクの単体テストコード

## 機器詳細
高感度マイクアンプキット  
https://akizukidenshi.com/catalog/g/gK-05757/

## 回路図
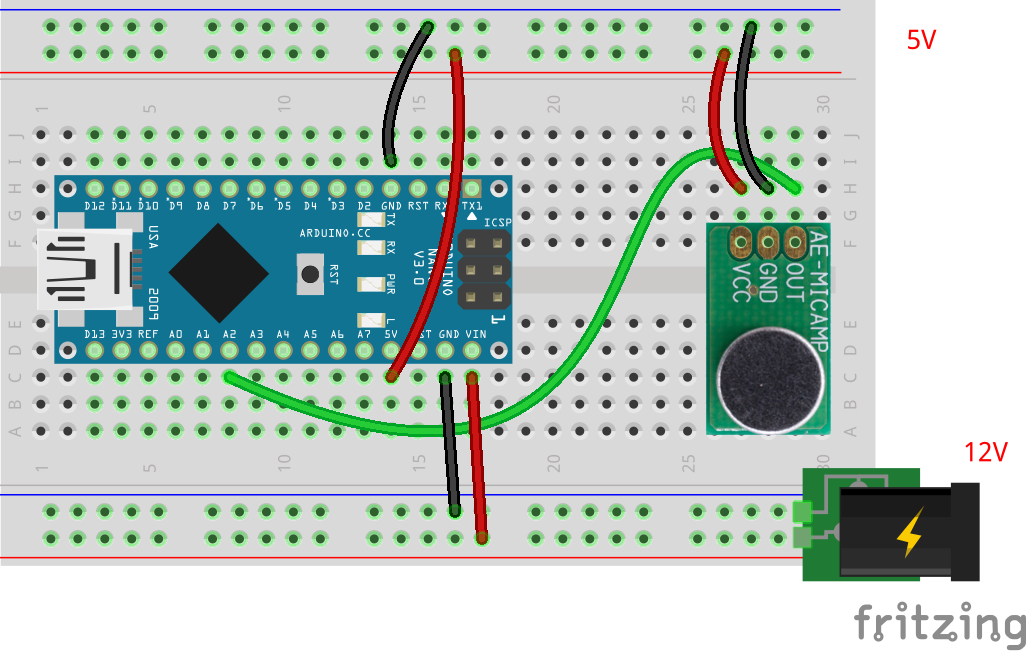
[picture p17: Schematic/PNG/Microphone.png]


+ 音圧をアナログ入力で読み取る
+ 声や拍手などの大きな音をトリガとしたプログラムを書くときに利用できる

## ソースコードへのリンク
[GitHub](https://github.com/meltingrabbit/CanSatForHighSchoolStudents/tree/master/Arduino/Test_Microphone)

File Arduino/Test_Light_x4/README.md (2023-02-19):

# 光センサの単体テストコード（４並列版）
## 概要
光センサの単体テストコード（４並列版）  
[光センサの単体テスト](../Test_Light) を４並列にしたもの．  
これによって，どこから光が来ているかの方向が推定できる．  
回路図などの詳細は[光センサの単体テスト](../Test_Light)を参照すること．

## 機器詳細
ＣｄＳセル　５ｍｍタイプ  
http://akizukidenshi.com/catalog/g/gI-00110/

## 回路図
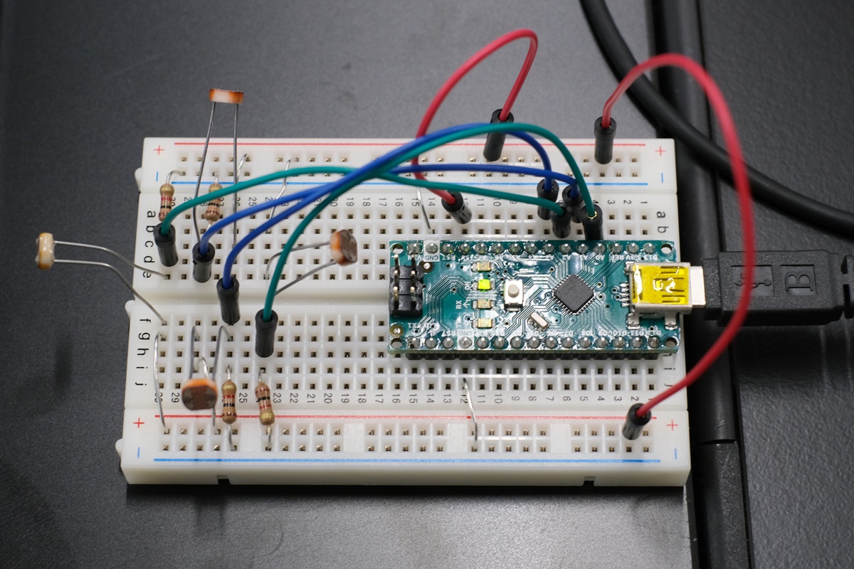
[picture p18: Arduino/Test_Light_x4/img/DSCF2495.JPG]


## ソースコードへのリンク
[GitHub](https://github.com/meltingrabbit/CanSatForHighSchoolStudents/tree/master/Arduino/Test_Light_x4)

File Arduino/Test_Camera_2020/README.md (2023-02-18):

# カメラ（2020年度使用版）の単体テストコード
## 概要
カメラ（2020年度使用版）の単体テストコード  
最新版は[こちら](../Test_SD)

SDカードについては
[こちら](../Test_SD)
を参照

## 機器詳細
TTLシリアルJPEGカメラ  
https://www.switch-science.com/catalog/1241/

## 回路図
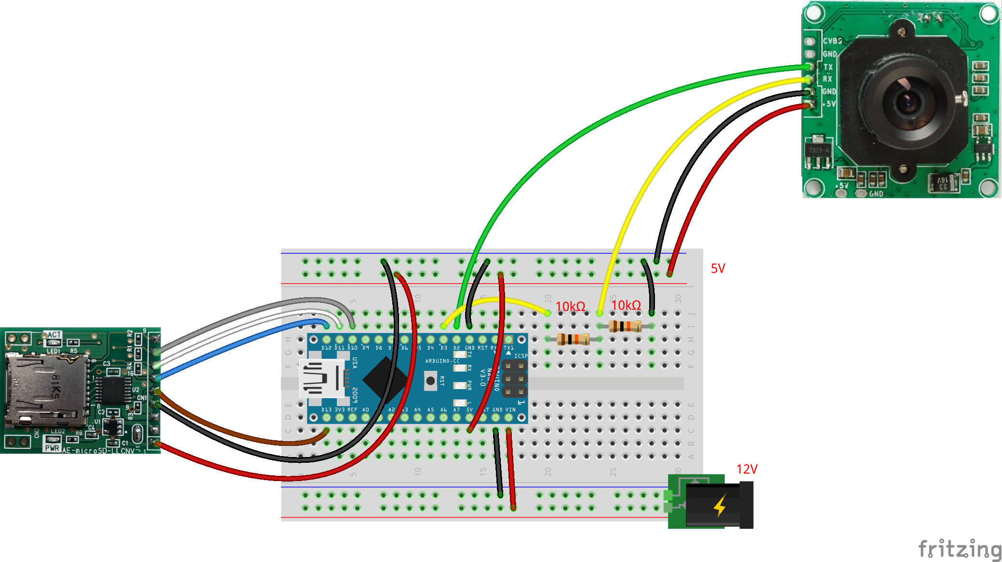
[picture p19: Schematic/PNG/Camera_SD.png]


| 素子 Pin | Arduino Pin | 備考 |
| ---- | ---- | ---- |
| TX | D2 | カメラの送信端子．Arduinoのシリアル受信端子と接続する． |
| RX | D3 | カメラの受信端子．Arduinoのシリアル送信端子と接続する．なお，途中で分圧をする． |
| GND | GND | GND |
| +5V | 5V | 5V 電源 |

+ 通信はシリアル通信 (TX, RX)
+ 電源電圧は5V
+ 通信電圧は3.3V
	- 受信側のみ，10kΩで分圧
+ カメラ側のピンのピッチが通常のブレッドボードは異なるので，ブレッドボードに直差ししたい場合はピッチ変換が必要
	- 実際には，撮影場所の自由度を増すために，ジャンプワイヤーの片側をはんだ付けして用いるのが便利で楽

## 撮影画像
上下逆に取り付けてしまた...（笑）



## 既知の問題
+ １枚目の撮像は必ず壊れた画像になる．

## ソースコードへのリンク
[GitHub](https://github.com/meltingrabbit/CanSatForHighSchoolStudents/tree/master/Arduino/Test_Camera_2020)

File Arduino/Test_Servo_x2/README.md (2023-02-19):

# サーボモータの単体テストコード（２並列版）
## 概要
サーボモータの単体テストコード（２並列版）  
[サーボモータの単体テスト](../Test_Servo) を４並列にしたもの．  
そろそろ許容電流量が気になるところ...（本当は電源ラインを別から引くべき）  
回路図などの詳細は[サーボモータの単体テスト](../Test_Servo)を参照すること．

## 機器詳細
マイクロサーボ　ＳＧ９２Ｒ  
http://akizukidenshi.com/catalog/g/gM-08914/

## 回路図
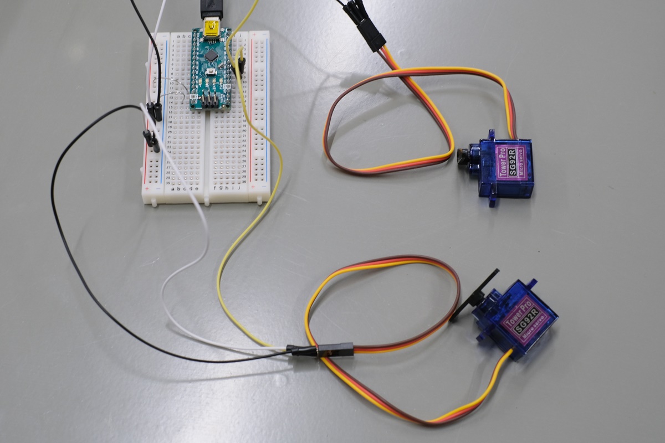
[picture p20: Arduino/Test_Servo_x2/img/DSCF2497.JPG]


## ソースコードへのリンク
[GitHub](https://github.com/meltingrabbit/CanSatForHighSchoolStudents/tree/master/Arduino/Test_Servo_x2)

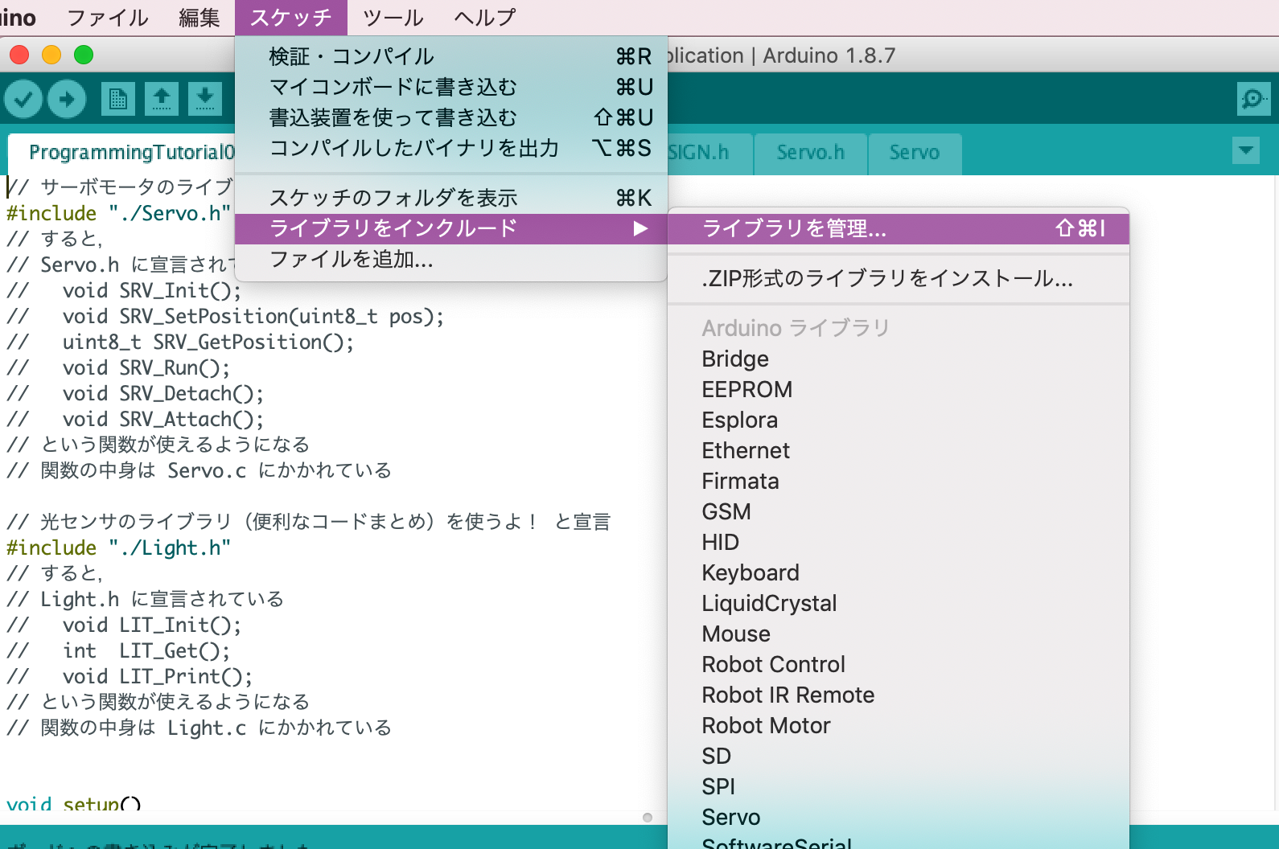
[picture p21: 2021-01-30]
Arduino/Test_Servo/img/Servo_lib_update1.png

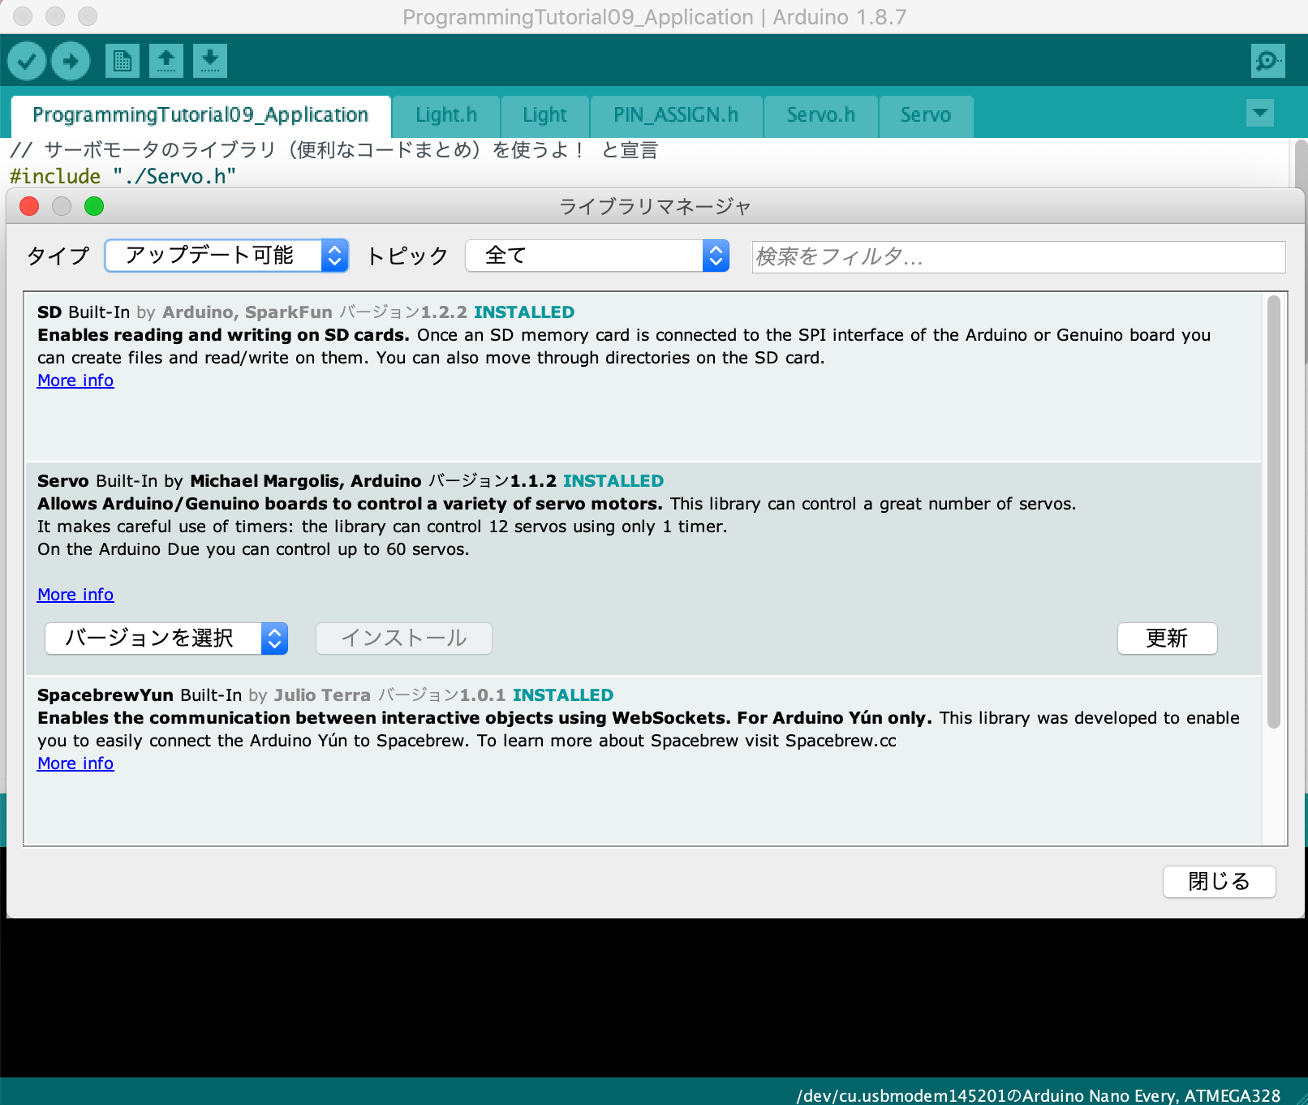
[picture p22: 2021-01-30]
Arduino/Test_Servo/img/Servo_lib_update2.png

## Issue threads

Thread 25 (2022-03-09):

回路図に結線表を追記する

meltingrabbit, 2022-03-09:
https://github.com/meltingrabbit/CanSatForHighSchoolStudents/tree/f002dc8e3dab88c16f00ecb07299bff67f27c18f/Arduino/Test_Barometer_Thermohygrometer のようなもの

Closed 2022-03-15.

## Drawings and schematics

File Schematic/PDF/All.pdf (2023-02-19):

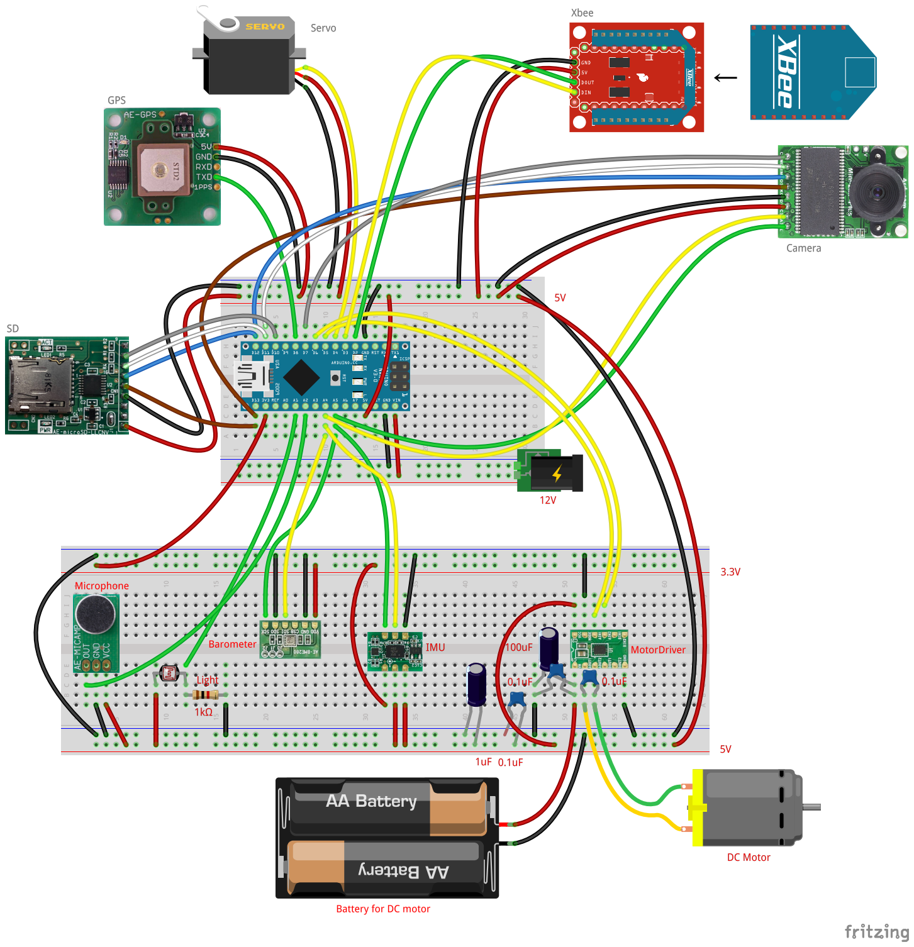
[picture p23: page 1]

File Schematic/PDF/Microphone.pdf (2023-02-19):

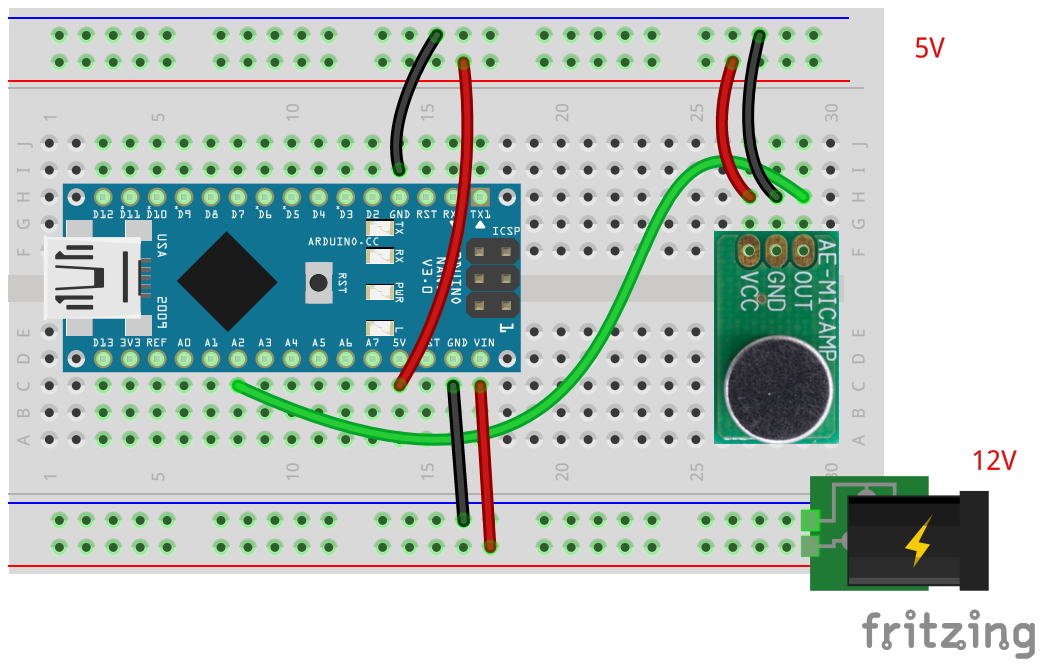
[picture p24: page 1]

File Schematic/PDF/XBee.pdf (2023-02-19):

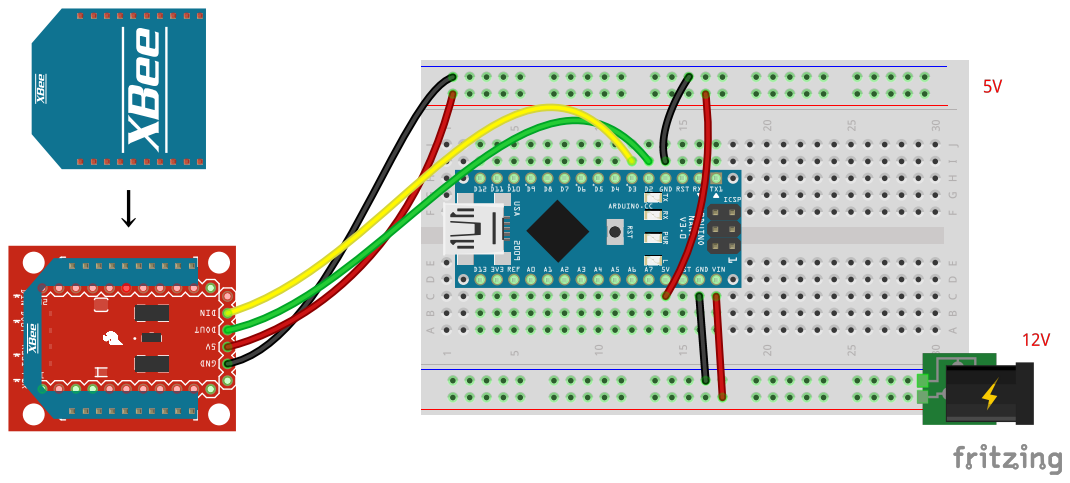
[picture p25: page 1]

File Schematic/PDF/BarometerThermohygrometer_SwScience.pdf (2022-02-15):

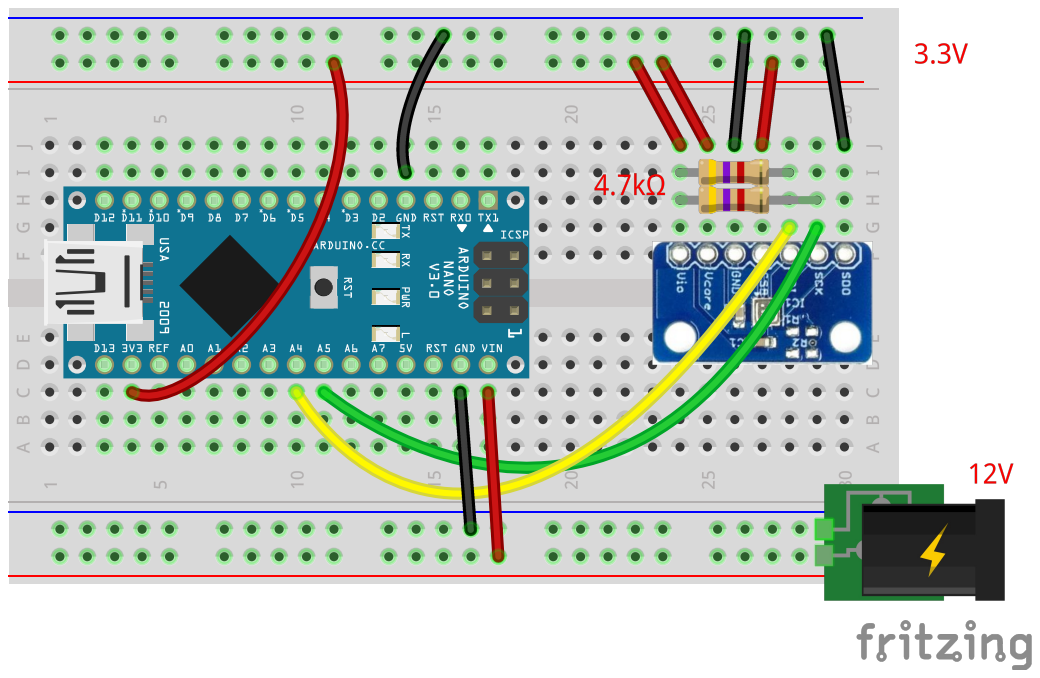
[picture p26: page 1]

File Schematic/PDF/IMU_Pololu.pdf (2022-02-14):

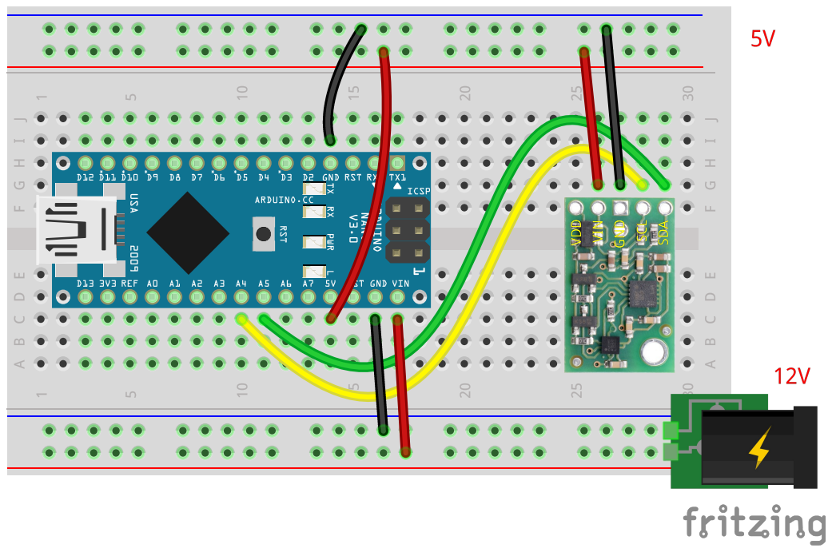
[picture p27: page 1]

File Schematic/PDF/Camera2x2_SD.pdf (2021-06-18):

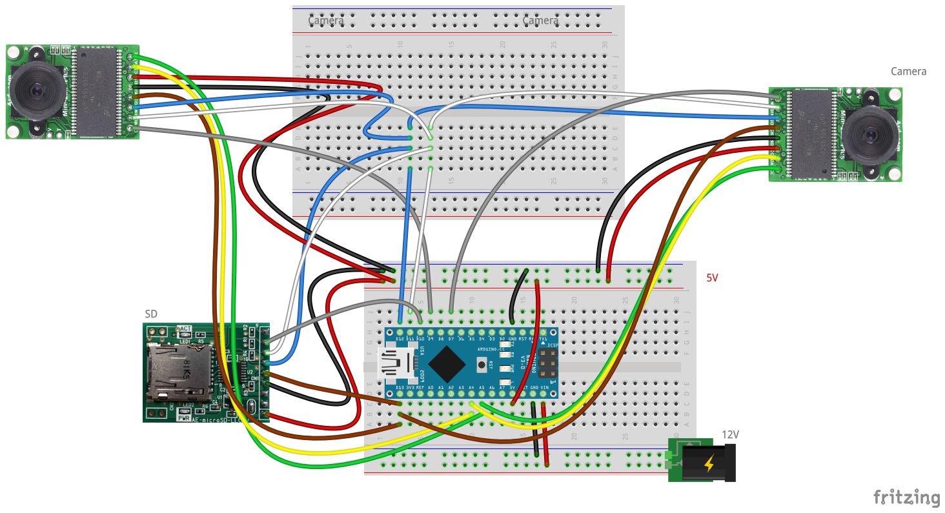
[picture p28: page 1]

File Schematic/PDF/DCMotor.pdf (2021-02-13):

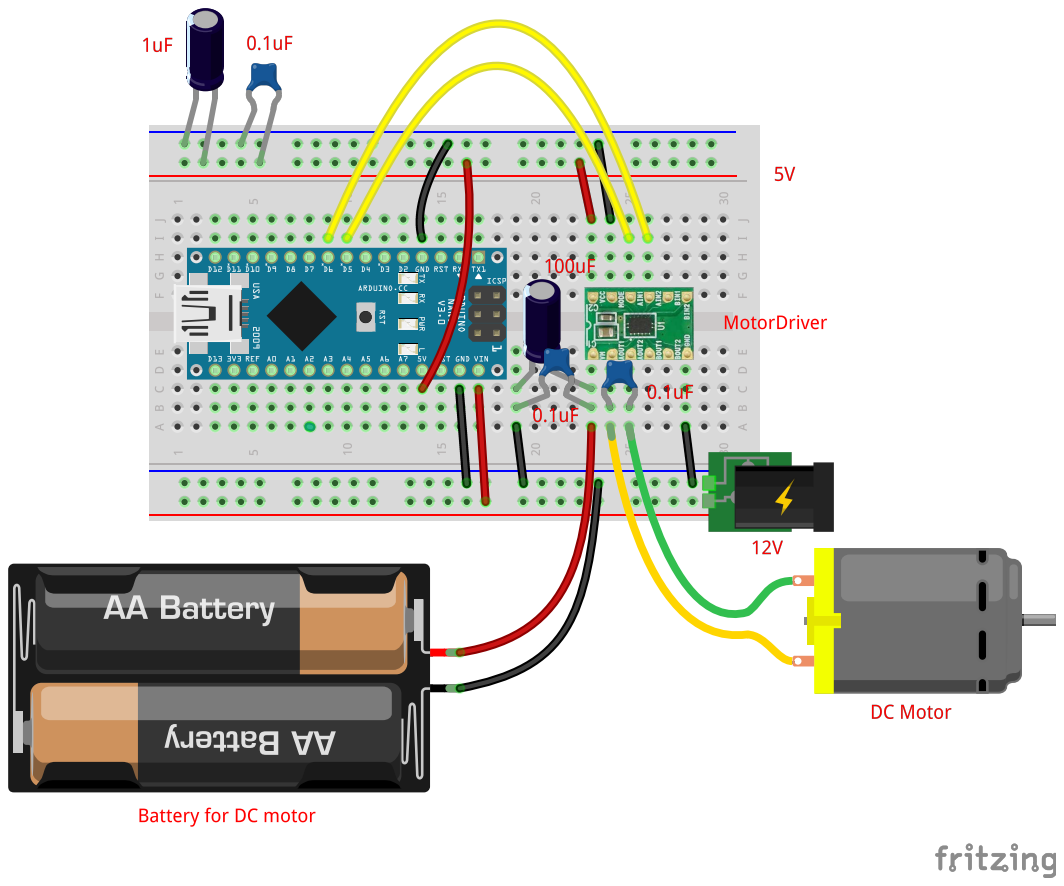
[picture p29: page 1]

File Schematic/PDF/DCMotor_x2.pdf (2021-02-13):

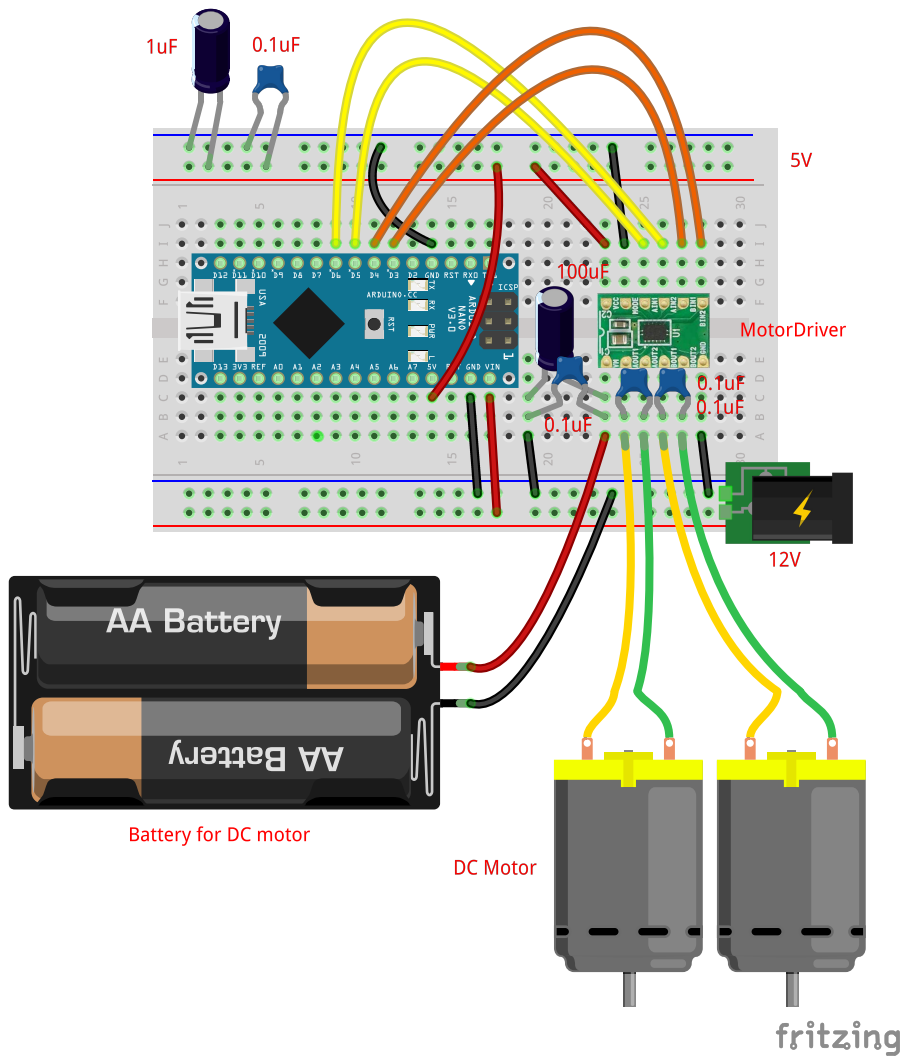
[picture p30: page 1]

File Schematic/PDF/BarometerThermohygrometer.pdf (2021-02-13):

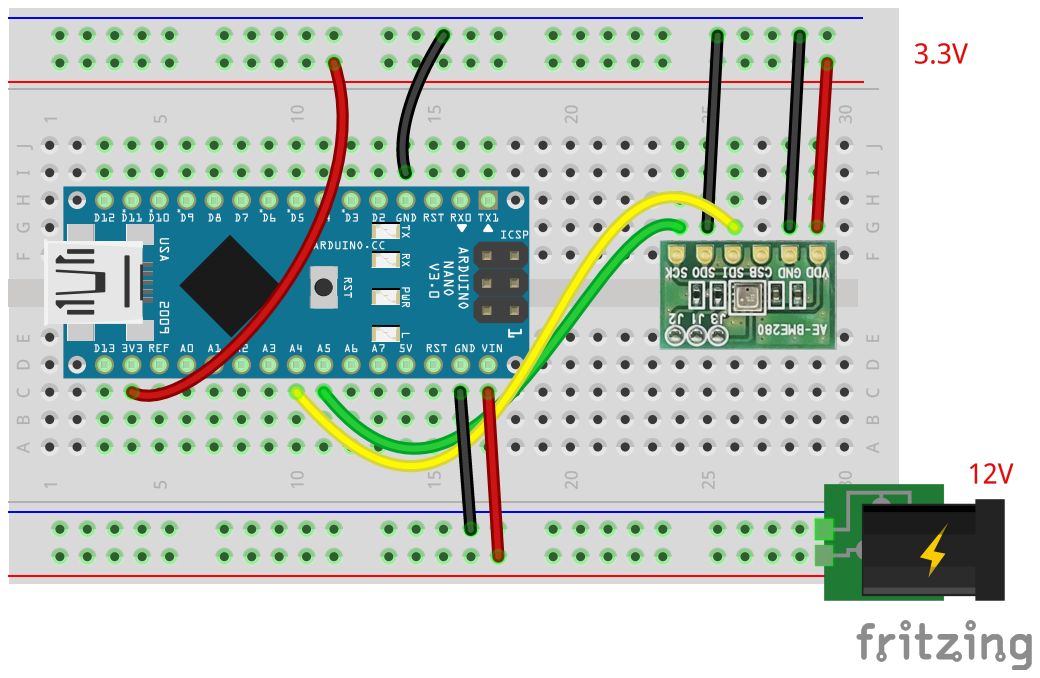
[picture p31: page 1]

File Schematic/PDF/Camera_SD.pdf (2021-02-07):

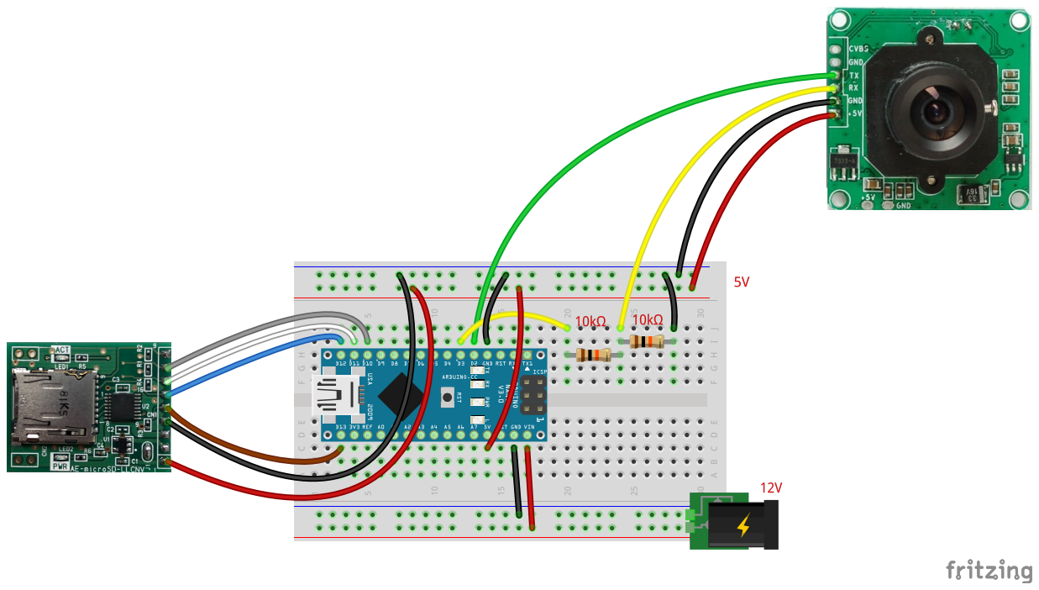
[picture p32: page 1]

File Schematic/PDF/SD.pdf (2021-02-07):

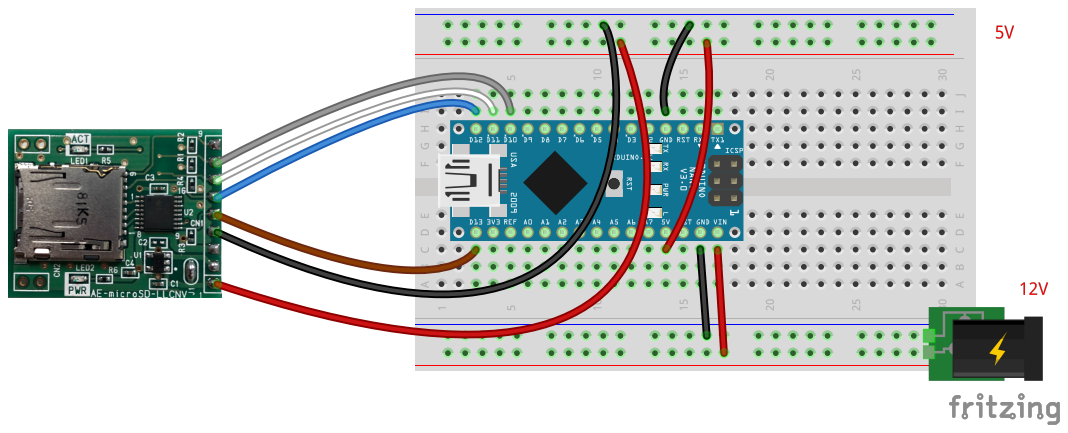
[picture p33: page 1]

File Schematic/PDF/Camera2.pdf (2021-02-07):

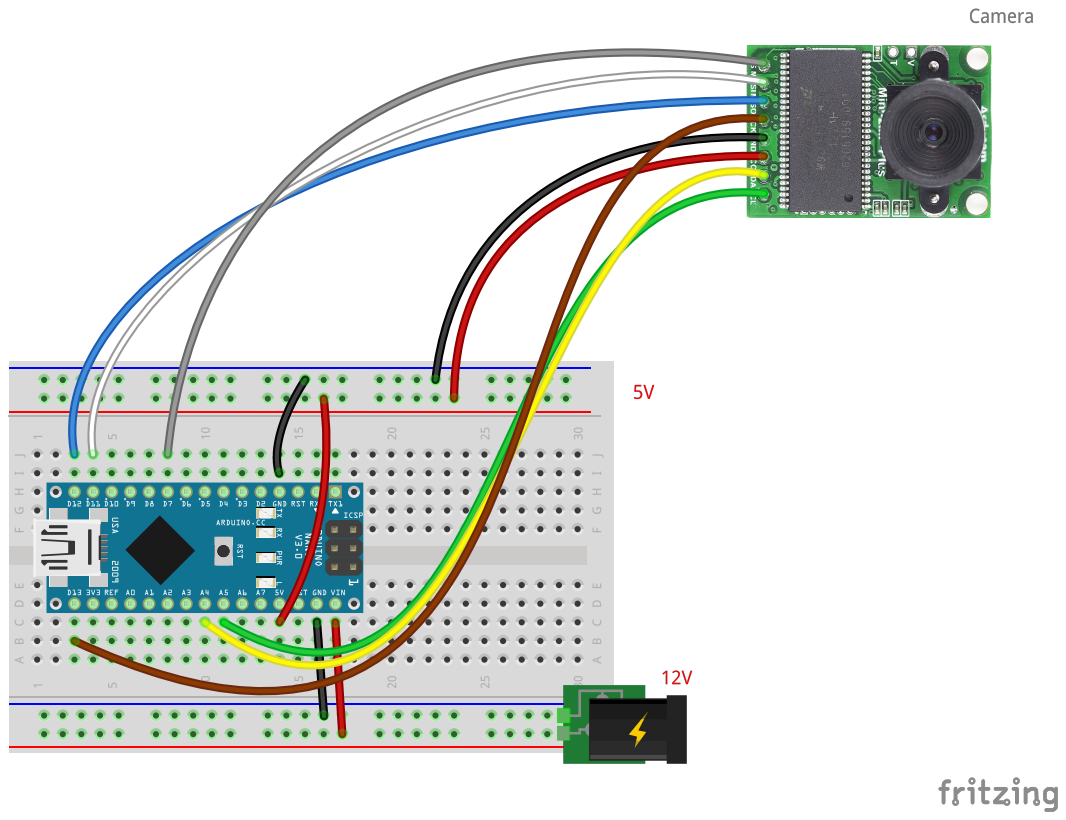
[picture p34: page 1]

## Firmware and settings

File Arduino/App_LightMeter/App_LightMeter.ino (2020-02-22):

#include "./Servo.h"
#include "./Light.h"

void setup()
{
	// デバック用シリアル通信は9600bps
	Serial.begin(9600);

	// サーボモータを初期化
	SRV_Init();
	// 光センサを初期化
	LIT_Init();

	Serial.println(F("Init done"));
	delay(300);
}

void loop()
{
	// 変数の初期化
	uint32_t light = 0;
	uint8_t  sampling_num = 20;

	// sampling_num回の平均値をとる
	for (int i = 0; i < sampling_num; i = i + 1) {
		light = light + LIT_Get();
	}
	light = light / sampling_num;

	// 明るさを角度に変換
	// lightは 0 - 1024
	// サーボは 0 - 180
	uint8_t angle = (uint8_t)( (float)light * 180.0 / 1024.0);

	// 表示
	Serial.print(F("Light = "));
	Serial.print(light);
	Serial.print(F(", Angle = "));
	Serial.println(angle);

	// サーボモータの角度をセット
	SRV_SetPosition(angle);
	// セットした角度にサーボモータを動かす
	SRV_Run();

	// 実行周期を調整
	delay(50);
}

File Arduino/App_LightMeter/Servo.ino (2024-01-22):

#include "./Servo.h"


Servo_t servo;

void SRV_Init() {
	servo.position = 0;
	servo.setPosition = 1;	// servo2.setPosition = 0 にするとサーボが振動してしまうため1で初期化している

	// servo.servo.attach(PIN_SRV);
	SRV_Attach();
	SRV_Run();

	// Serial.println(F("SRV init done"));
	Serial.println(F("SRV init done"));
}

void SRV_SetPosition(uint8_t pos) {
	servo.setPosition = pos;
}

uint8_t SRV_GetPosition() {
	return servo.position;
}


void SRV_Run() {
	servo.servo.write(servo.setPosition);
	servo.position = servo.setPosition;
}

void SRV_Detach() {
	servo.servo.detach();
}
void SRV_Attach() {
	servo.servo.attach(PIN_SRV);
	delay(5000);
}

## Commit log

2020-02-16 とりあえずのテストコード
2020-02-16 サーボの現在位置を取得できるように
2020-02-16 IMUのゲッター追加
2020-02-16 SDのログに時間を追加
2020-02-16 フォルダ名を変更
2020-02-16 1001にした
2020-02-16 Add Light Sensor (#3)
    * masterの更新を反映 (#2)
    * フォルダ名を変更
    * 1001にした
    * add light sensor
2020-02-16 merge from Sensor test. カメラの使用とメモリ削減 (#5)
    * Add Light Sensor (#3) (#4)
    * TX RXの定義を更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
2020-02-16 merge from Sensor test メモリの削減 (#7)
    * TX RXの定義を更新
    * 起動ご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
2020-02-16 メモリ削減
2020-02-16 メモリ使用量の削減
2020-02-16 メモリ節約
2020-02-16 メモリ節約とGPSの値保持
2020-02-16 コメント追加
2020-02-17 GPSの単体テストコードを追加
2020-02-17 光センサの単体テストコードを追加
2020-02-17 実行周期の変更
2020-02-17 IMUの単体テストコードを追加
2020-02-17 不足していたincludeを追加
2020-02-17 SDカードの単体テストコードを追加
2020-02-17 サーボモータの単体テストコードを追加
2020-02-17 サーボモータのバグfix
2020-02-17 カメラの単体テストコードを追加
2020-02-17 テストコードにサーボモータを追加
2020-02-17 回路図の追加
    [Camera.fzz, GPS.fzz, Light.fzz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]
2020-02-17 気圧計のテストコードの初版．ここからメモリを減らしていく
2020-02-17 GPSのテストコードの説明を追加
2020-02-17 電圧値を追加
    [Camera.fzz, GPS.fzz, Light.fzz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]
2020-02-17 気圧計を統合したが，メモリ不足
2020-02-17 IMU回路図を追加
    [IMU.fzz]
2020-02-17 merge from Test barometer2 : ライブラリからの脱却．メモリ削減 (#10)
    * メモリを削減
    * ライブラリからの脱却
    * ライブラリからの脱却
    * ライブラリを使ったコードを追加
    * メモリ削減
2020-02-17 Light回路図のミスを改修
    [Light.fzz]
2020-02-17 気圧計をライブラリレスに
2020-02-17 サーボのプルプルを防ぐ
2020-02-17 気圧計回路を追加
    [Barometer.fzz]
2020-02-17 単体テストコードの説明書を追加
2020-02-17 説明書の更新
2020-02-17 Servo回路図の画像を追加
    [Servo.fzz]
2020-02-17 CameraとSD回路図の追加
    [Camera_SD.fzz]
2020-02-17 カメラの説明書を更新
2020-02-17 IMUのミス(GND未接続)を修正
    [IMU.fzz]
2020-02-17 すべてを繋げた回路図の追加
    [All.fzz]
2020-02-18 誤植修正
2020-02-18 merge from Make documents (#11)
    * コメントやドキュメントの整備
    * add link from top readme
    * add all test link
    * add barometer URL
    * update document
    * update pin assign
2020-02-18 気圧計のコードを改良
2020-02-19 回路図中の文字を修正
    [All.fzz]
2020-02-19 再度コミット
    [All.fzz]
2020-02-20 構造などを追加
2020-02-20 画像サイズを縮小
2020-02-20 もろもろのチュートリアルプログラムを追加
2020-02-20 実装例などを追加
2020-02-21 現在の角度と光量を表示
2020-02-21 撮影画像を追加
2020-02-21 プログラミング演習の解説を追加
2020-02-21 add programming toutorial of Device Use
2020-02-21 提供関数の宣言を前に
2020-02-22 コメントを追加
2020-02-22 add servo2
2020-02-22 GPS のバグを解消
2020-02-22 bug fix at GPS
    [GPS.ino]
2020-02-22 詳細画像追加
2020-02-22 画像追加
2020-02-22 add switch
2020-02-22 IDEのリンクを追加
2020-02-22 スイッチの説明追加
2020-02-22 カメラのバグの説明を追加
2020-02-22 横幅調整
2020-02-22 IMUのGND線引き直し
    [IMU.fzz]
2020-02-23 IMU回路のミスを修正
    [IMU.fzz]
2020-02-23 IMUのバグを修正
2020-02-23 GPSのGeterを追加
2020-02-25 パーツリストフォルダの追加
2020-02-25 マイコン行と表を追加
2020-02-25 センサ行と表の追加
2020-02-25 リンクを改修
2020-02-25 リンクを再修正
2020-02-25 リンクを再々修正
2020-02-25 アクチュエータ・カメラの行と表を追加
2020-02-25 その他基板実装パーツの行と表を追加
2020-02-25 SDとスイッチのリンクを追加
2020-02-25 スイッチリンクの場所ミスを修正
2020-02-25 その他基板実装パーツの追記
2020-02-25 構造部材の行と表を追加
2020-02-25 周辺機器の行と表を追加
2020-03-02 カメラ行の位置を変更、一部パーツ型番のミスを修正
2020-10-24 add schematic of XBee
    [XBee.fzz]
2021-01-30 add baro thermo humid sensor
2021-01-30 update baro thermo humid sensor code
2021-01-30 fix for nano every (#12)
    [ProgrammingTutorial06_Function.ino]
2021-01-30 fix litght pin
2021-02-06 add about arduino
2021-02-06 add sensor
2021-02-07 fix schematics for new components (#13)
    * fix schematics for new components
    * change jumper color
    * change jumper color
    * modify jumper color for readablility
    * remove comment
    [All.fzz, BarometerThermohygrometer.fzz, Camera2.fzz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]
2021-02-07 modify SD code color
    [Camera_SD.fzz, SD.fzz]
2021-02-07 Feature/modify tutorial07 (#14)
    * modify outputs
    * edit readme
    * edit commentout
    * fix
    [Barometer.ino, BarometerThermohygrometer.ino, ProgrammingTutorial07_Device1.ino]
2021-02-07 fix pin assign
2021-02-07 fix schematic (#15)
    * fix schematic
    * fix driver pin
    * fix driver pin
    * modify XBee
    * add dcmotor
    * fix subtle point
    [All.fzz, DCMotor.fzz, XBee.fzz]
2021-02-08 add board image
2021-02-08 add pin assign fig
2021-02-13 fix bth borad fig
    [BarometerThermohygrometer.fzz]
2021-02-13 fix dc motor schematic
    [DCMotor.fzz]
2021-02-13 fix all schematic
    [All.fzz]
2021-02-13 add dcmotor x 2
    [DCMotor_x2.fzz]
2021-02-13 add text for dc motor on schematic
    [All.fzz, DCMotor.fzz]
2021-02-13 add dc motor x2 on top page
2021-02-13 add capacitor for dc moter
    [All.fzz, DCMotor.fzz, DCMotor_x2.fzz]
2021-06-18 add 2 cameras schematic
    [Camera2x2_SD.fzz]
2021-06-18 modify src for 2 cameras
2021-06-19 add kagakugijutu
    生徒が自ら書いたコード
2022-02-14 add sw science BME280
    [BarometerThermohygrometer_SwScience.fzz]
2022-02-14 fix BMX055 IMU
2022-02-14 add sw science imu
    [IMU_Pololu.fzz]
2022-02-14 add link to about arduino
2022-02-15 add schematic table to bme280
2022-02-15 fix fig
    [BarometerThermohygrometer_SwScience.fzz]
2022-03-15 add gps schematic table
2022-03-15 add IMU schematic table
2022-03-15 add servo schematic table
2022-03-15 add motor schematic table
2022-03-15 add barometer schematic table
2022-03-15 add xbee schematic table
2022-03-15 add sd schematic table
2022-03-15 add camera schematic table
2022-03-15 add battery board
2022-03-19 fix img of power board
2022-03-19 fix code of hello world
    [ProgrammingTutorial01_HelloWorld.ino]
2022-03-19 fix var sample
2022-03-19 fix if else code
    [ProgrammingTutorial04_IfElse.ino]
2022-03-19 fix device
2022-03-19 add device 3
2023-02-18 fix camera path
2023-02-19 add mic fig
    [All.fzz, Microphone.fzz]
2023-02-19 add sample code for microphone
2023-02-19 fix pin assigned name
    [Microphone.ino]
2023-02-19 update pin assing
2023-02-19 update xbee fig
    [XBee.fzz]
2023-02-19 fix Servo initializer
2023-02-19 add comment about Servo
2023-02-24 sed 3月 2月
